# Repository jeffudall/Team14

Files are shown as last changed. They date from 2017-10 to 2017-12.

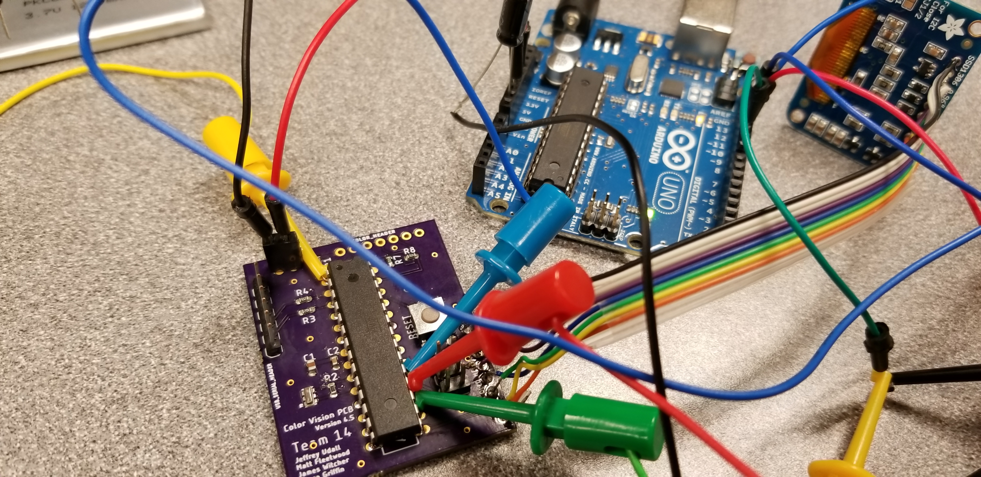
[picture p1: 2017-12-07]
images/20171201_192201.jpg

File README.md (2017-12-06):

Welcome to Team 14's Practicum Pages - ECE 411 Fall 2017

This repository will document our practicum project for the ECE 411 Industrial Design course at PSU for Fall 2017. Here you will find details of our project creation as well as documentation detailing the specifications and operation of our final product - a color scanner device.

Team members:

- Matthew Fleetwood fleet@pdx.edu
- Bruce Griffin bruce7@pdx.edu
- Jeffrey Udall judall@pdx.edu
- James Witcher jwitcher@pdx.edu

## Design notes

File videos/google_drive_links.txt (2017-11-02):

Not sure how to upload videos (larger than 25 MB not accepted?) to git. 

Here's the google drive link to the video of the speaker working with the RGB sensor:

https://drive.google.com/a/pdx.edu/file/d/0B2xjN2Vtsn0jbUI3cDFJcDRBUm8/view?usp=sharing

Video of new LCD demo

https://drive.google.com/open?id=0B6vxZIn4T96eQ21icXgxQTdLRFE

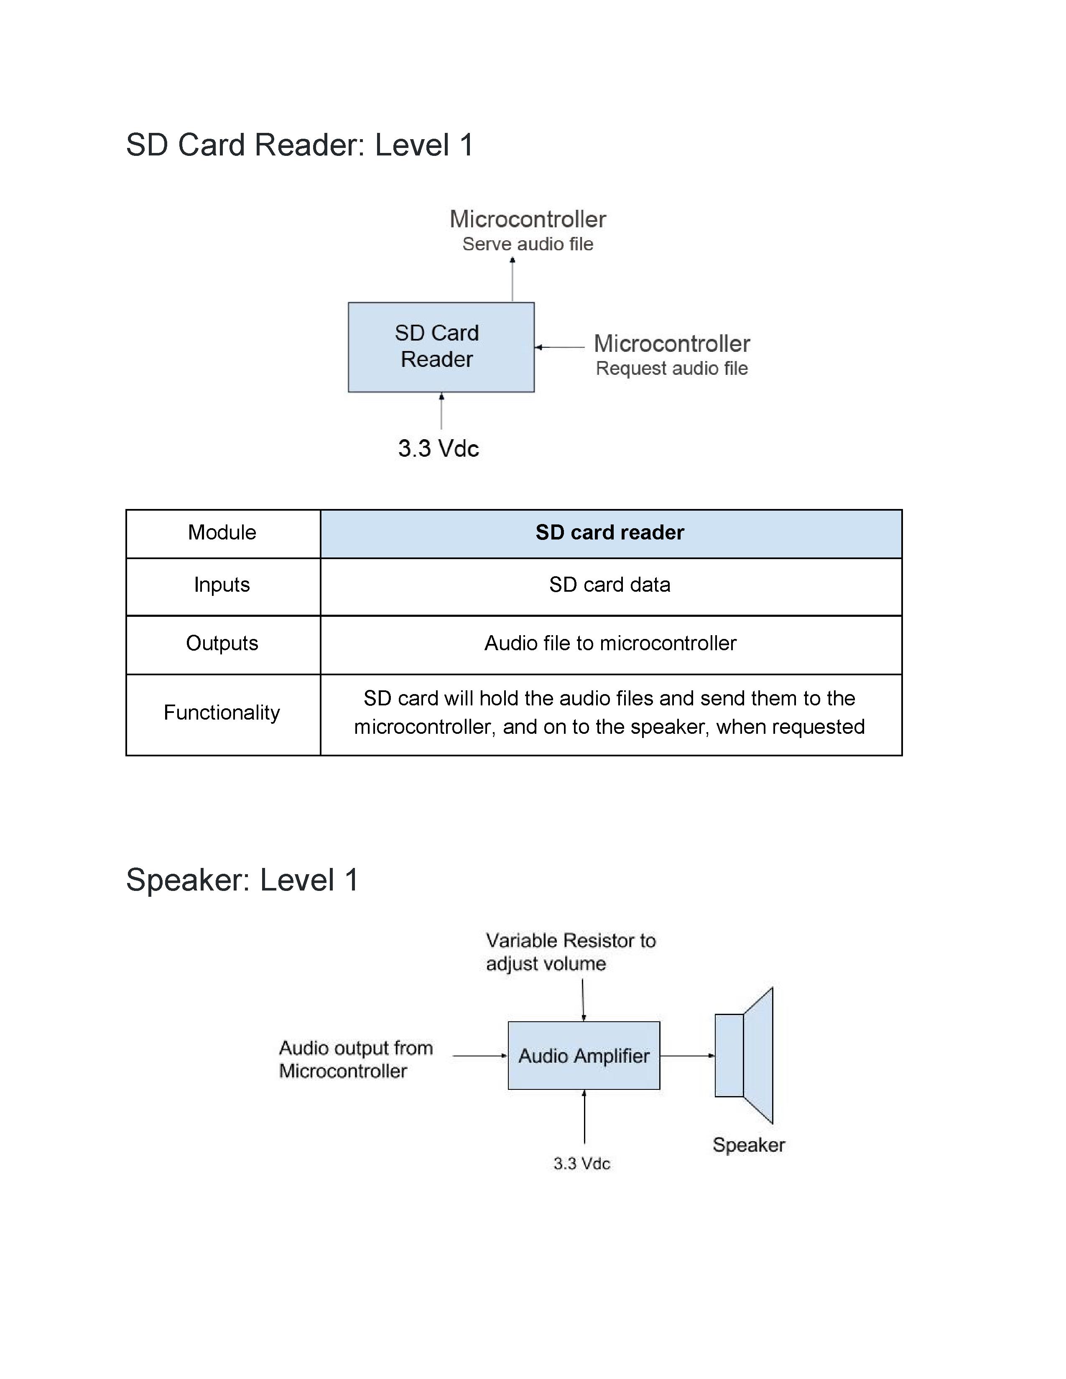
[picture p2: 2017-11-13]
images/HW5_group14_draft01-5.jpg

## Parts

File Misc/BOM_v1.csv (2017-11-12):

Part | Value | Device | Package | Description
C6 | 100n | C-EU0603-RND | C0603-ROUND | CAPACITOR, European symbol
COLOR_HEADER | COLOR_HEADER | HEADER-1X770MIL | 1X07_ROUND_70 | PIN HEADER
D2 | CD1206-S01575 | DIODE-MINIMELF | MINIMELF | DIODE
ICSP | 3x2 M | PINHD-2X3 | 2X03 | PIN HEADER
OLED_HEADER | OLED_HEADER | HEADER-1X870MIL | 1X08_ROUND_70 | PIN HEADER
POWER_IN | POWER_IN | PINHD-1X6 | 1X06 | PIN HEADER
POWER_SWITCH | POWER_SWITCH | EG1218S | EG1218 | SLIDING SWITCH
PSW_HEADER | PSW_HEADER | PINHD-1X6CB | 1X06-CLEANBIG | PIN HEADER
R2 | 1M | R-EU_R0603 | R0603-ROUND | RESISTOR, European symbol
RESET | TS42031-160R-TR-7260 | TS42 | TS42 | TS42
RN3 | 10K | 4R-NCAY16 | CAY16 | Array Chip Resistor
RN4 | 1K | 4R-NCAY16 | CAY16 | Array Chip Resistor
SCAN_BUTTON | SCAN_BUTTON | 31-XX | B3F-31XX | OMRON SWITCH
USB_SERIAL_HEADER | USB_SERIAL_HEADER | PINHD-1X6 | 1X06 | PIN HEADER
Y2 | CSTCE16M0V53-R0 16MHZ | RESONATORMU | RESONATOR
ZU4 | ATMEGA328P-PU | ATMEGA328P-PU | DIL28-3 | MICROCONTROLLER

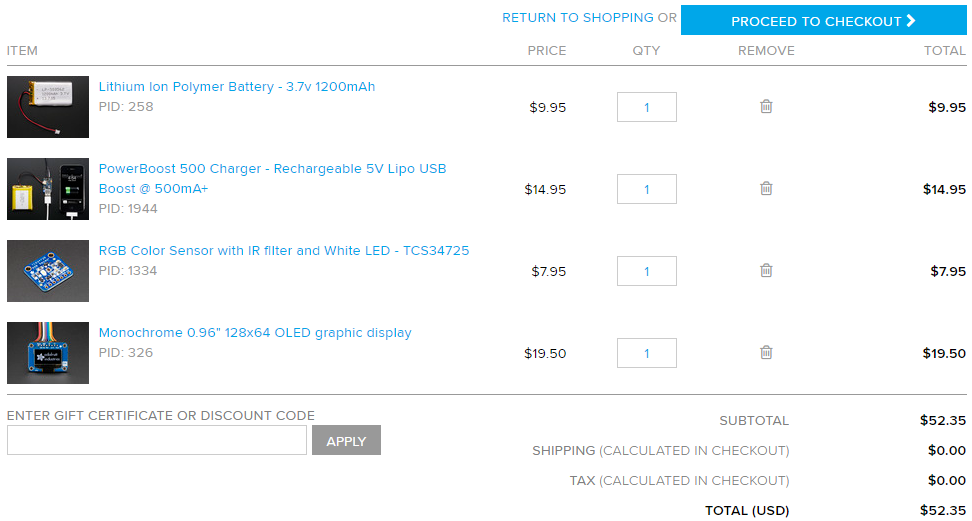
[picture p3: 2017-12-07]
images/bom.PNG

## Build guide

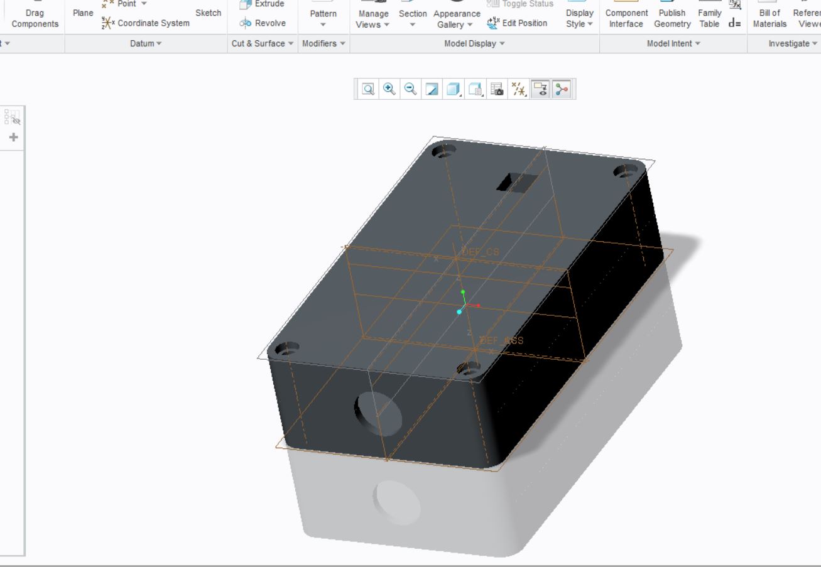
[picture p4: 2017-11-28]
images/Assemble_V2.JPG

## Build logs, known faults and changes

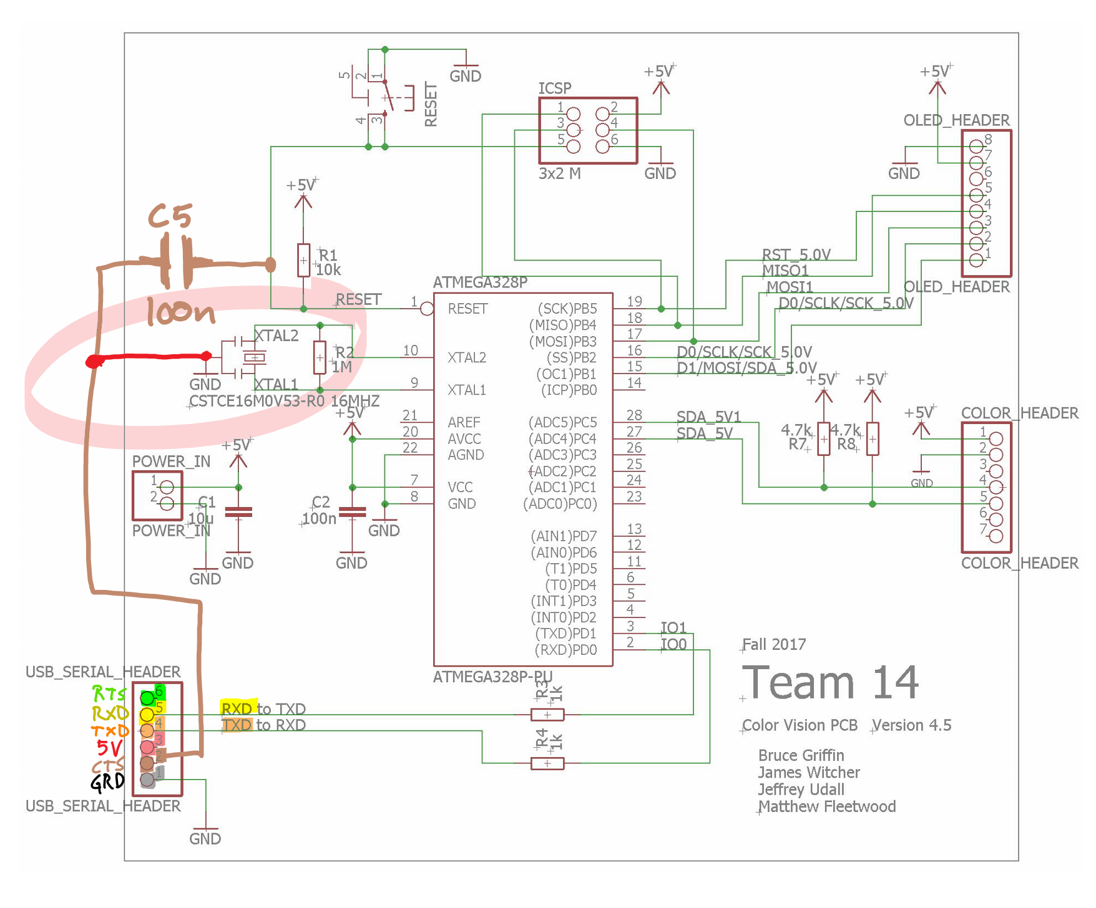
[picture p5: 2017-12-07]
images/Programing chip/Troubleshooting/Pasted image at 2017_12_03 10_22 AM (1).png

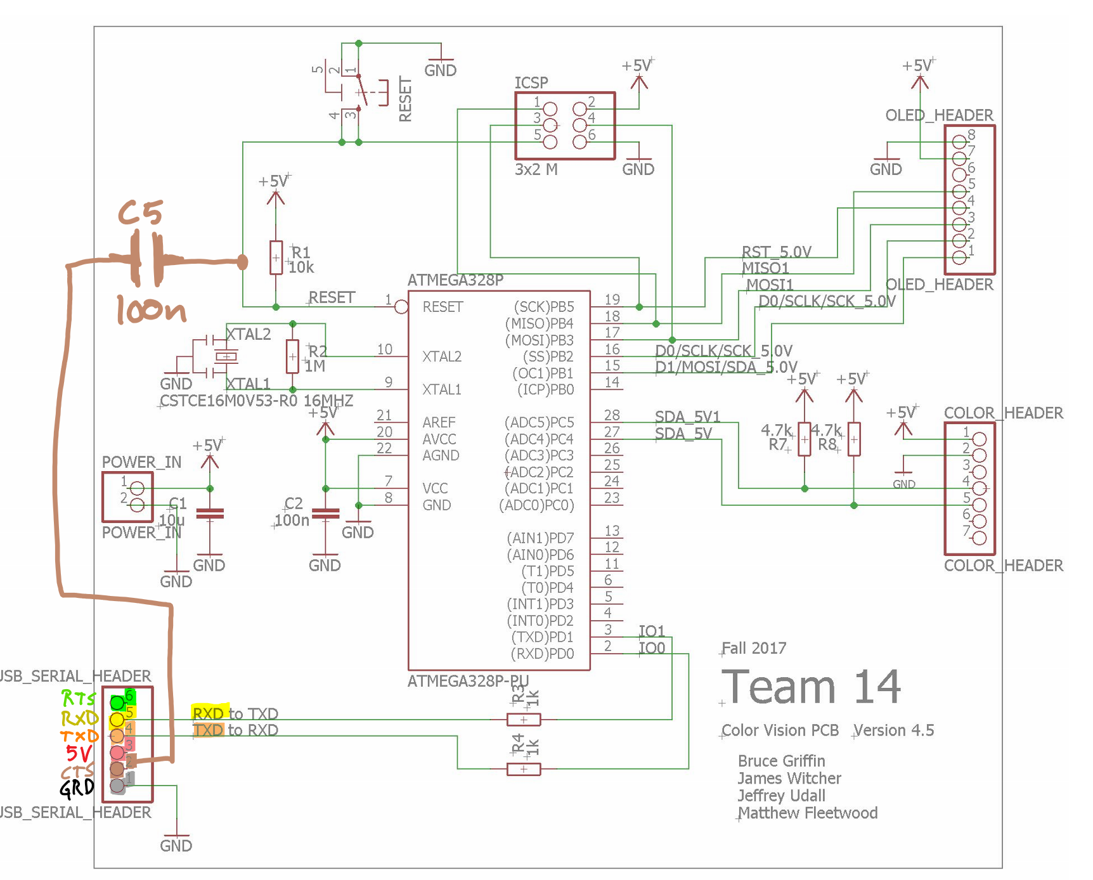
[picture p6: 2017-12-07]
images/Programing chip/Troubleshooting/Pasted image at 2017_12_03 10_20 AM.png

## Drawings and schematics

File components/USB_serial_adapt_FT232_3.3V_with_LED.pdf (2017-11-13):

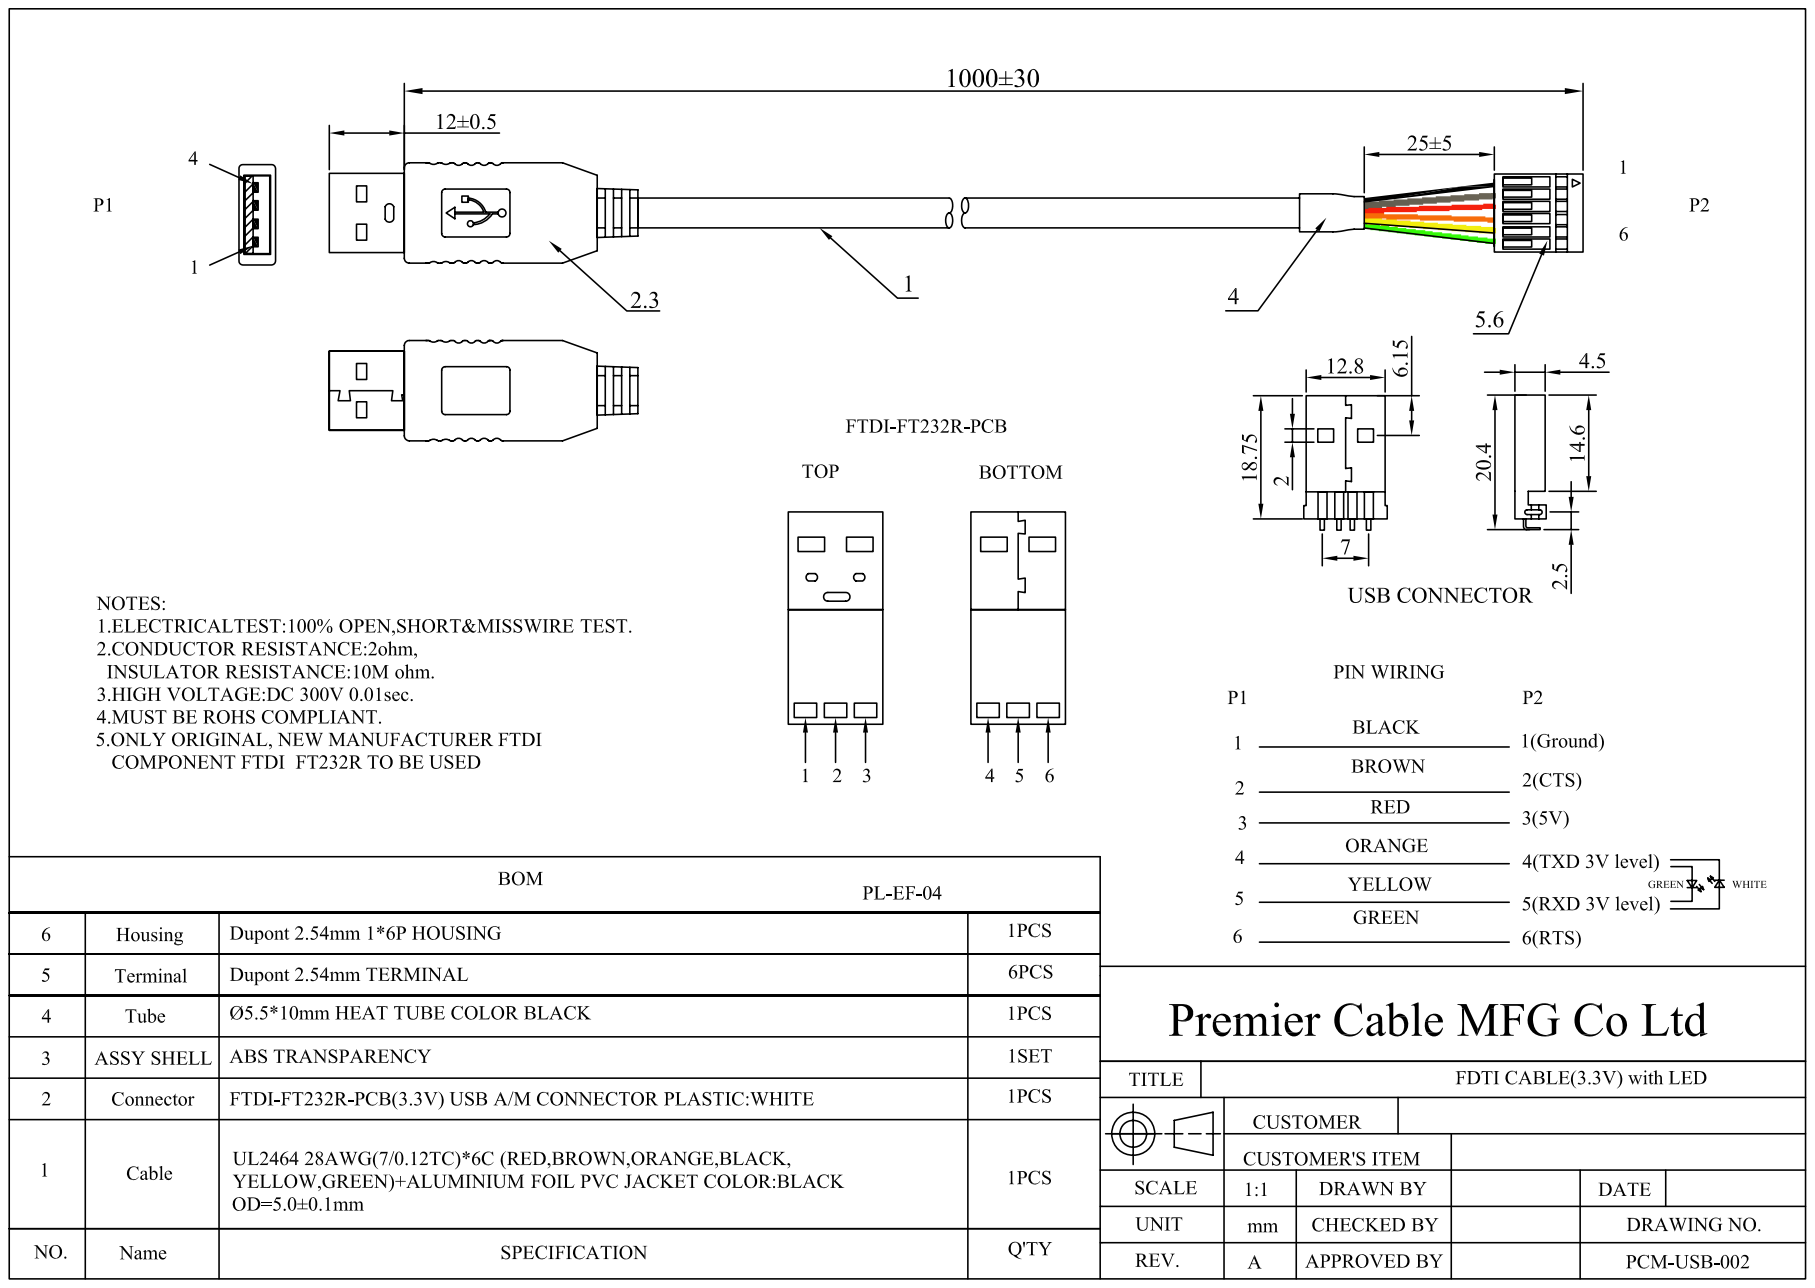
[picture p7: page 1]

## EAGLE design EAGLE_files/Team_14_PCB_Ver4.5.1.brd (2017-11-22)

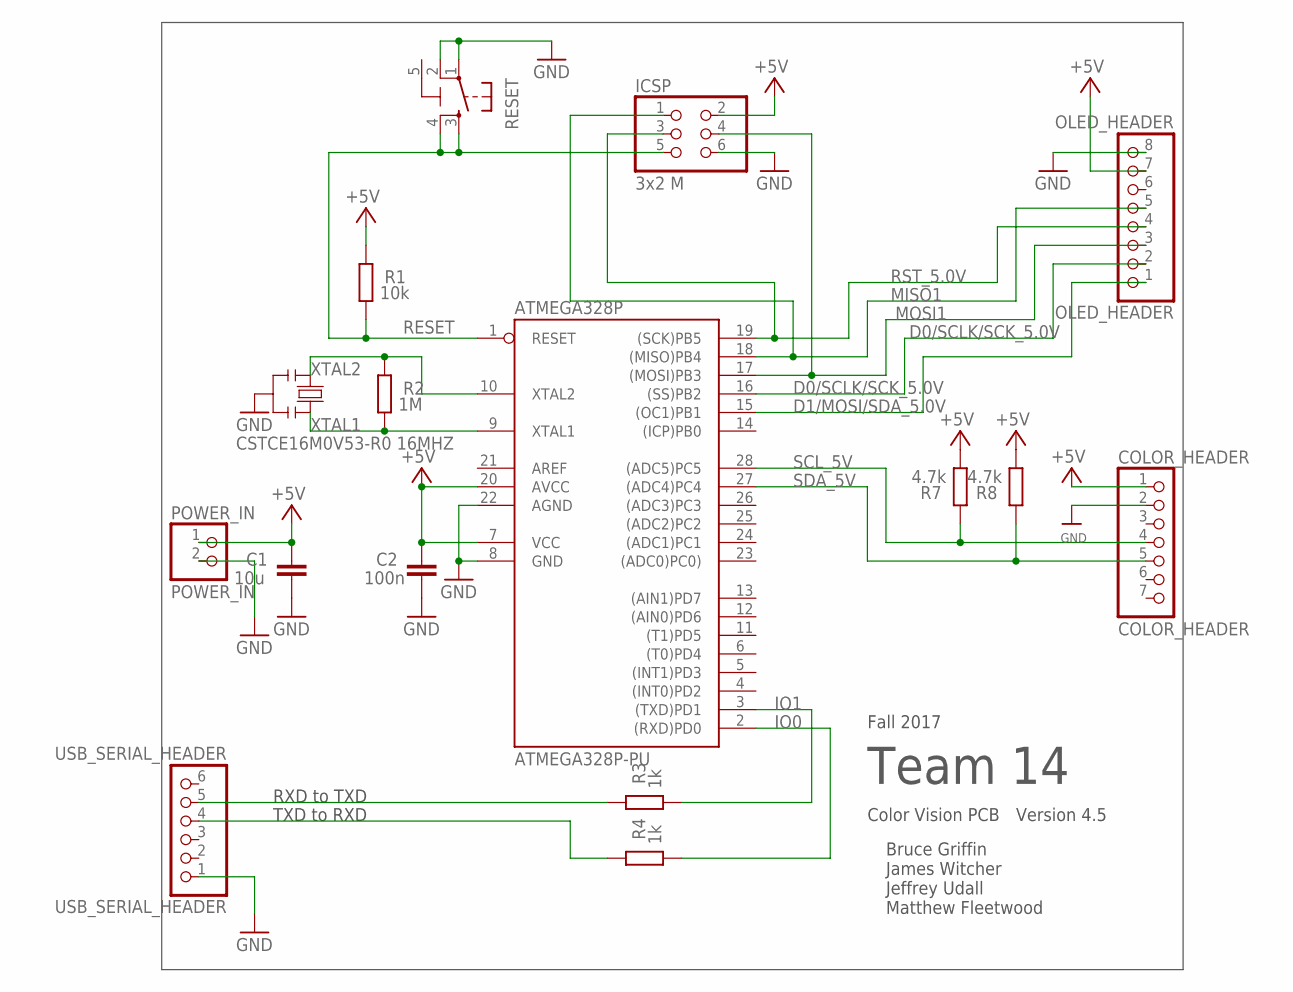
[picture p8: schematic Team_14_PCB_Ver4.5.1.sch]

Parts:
ATMEGA328P: ATMEGA328P-PU; DIL28-3
C1: 10u; C0603-ROUND
C2: 100n; C0603-ROUND
COLOR_HEADER: COLOR_HEADER; 1X07_ROUND_70
ICSP: 3x2 M; 2X03
OLED_HEADER: OLED_HEADER; 1X08_ROUND_70
POWER_IN: POWER_IN; 1X02
R1: 10k; R0603-ROUND
R2: 1M; R0603-ROUND
R3, R4: 1k; R0603-ROUND
R7, R8: 4.7k; R0603-ROUND
RESET: TS42
USB_SERIAL_HEADER: USB_SERIAL_HEADER; 1X06
Y2: CSTCE16M0V53-R0 16MHZ; RESONATOR

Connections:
5-GND: RESET.5 (5-GND)
+5V: ATMEGA328P.7 (VCC), ATMEGA328P.20 (AVCC), C1.2, C2.2, COLOR_HEADER.1, ICSP.2, OLED_HEADER.7, POWER_IN.1, R1.2, R7.1, R8.1
D0/SCLK/SCK_5.0V: ATMEGA328P.16 ((SS)PB2), OLED_HEADER.2
D1/MOSI/SDA_5.0V: ATMEGA328P.15 ((OC1)PB1), OLED_HEADER.1
GND: ATMEGA328P.8 (GND), ATMEGA328P.22 (AGND), C1.1, C2.1, COLOR_HEADER.2, ICSP.6, OLED_HEADER.8, POWER_IN.2, RESET.1, RESET.2, USB_SERIAL_HEADER.1, Y2.2
IO0: ATMEGA328P.2 ((RXD)PD0), R4.1
IO1: ATMEGA328P.3 ((TXD)PD1), R3.1
MISO1: ATMEGA328P.18 ((MISO)PB4), ICSP.1, OLED_HEADER.5
MOSI1: ATMEGA328P.17 ((MOSI)PB3), ICSP.4, OLED_HEADER.3
unnamed: R3.2, USB_SERIAL_HEADER.5
unnamed: R4.2, USB_SERIAL_HEADER.4
RESET: ATMEGA328P.1 (RESET), ICSP.5, R1.1, RESET.3, RESET.4
RST_5.0V: ATMEGA328P.19 ((SCK)PB5), ICSP.3, OLED_HEADER.4
SCL_5V: ATMEGA328P.28 ((ADC5)PC5), COLOR_HEADER.4, R7.2
SDA_5V: ATMEGA328P.27 ((ADC4)PC4), COLOR_HEADER.5, R8.2
XTAL1: ATMEGA328P.9 (XTAL1), R2.1, Y2.3
XTAL2: ATMEGA328P.10 (XTAL2), R2.2, Y2.1

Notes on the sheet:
Team 14
Bruce Griffin James Witcher Jeffrey Udall Matthew Fleetwood
Color Vision PCB
Version 4.5
Fall 2017
RXD to TXD
TXD to RXD

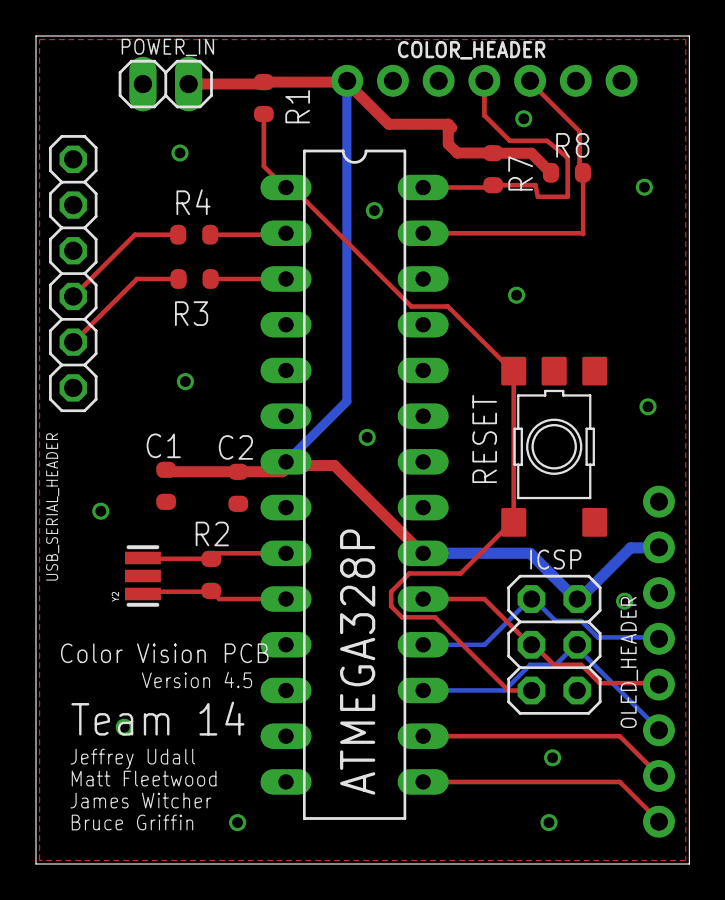
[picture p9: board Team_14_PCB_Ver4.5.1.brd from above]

Board: 2 copper layers, 36.3 x 46.0 mm, 16 parts (0 on the bottom side), 16 nets.

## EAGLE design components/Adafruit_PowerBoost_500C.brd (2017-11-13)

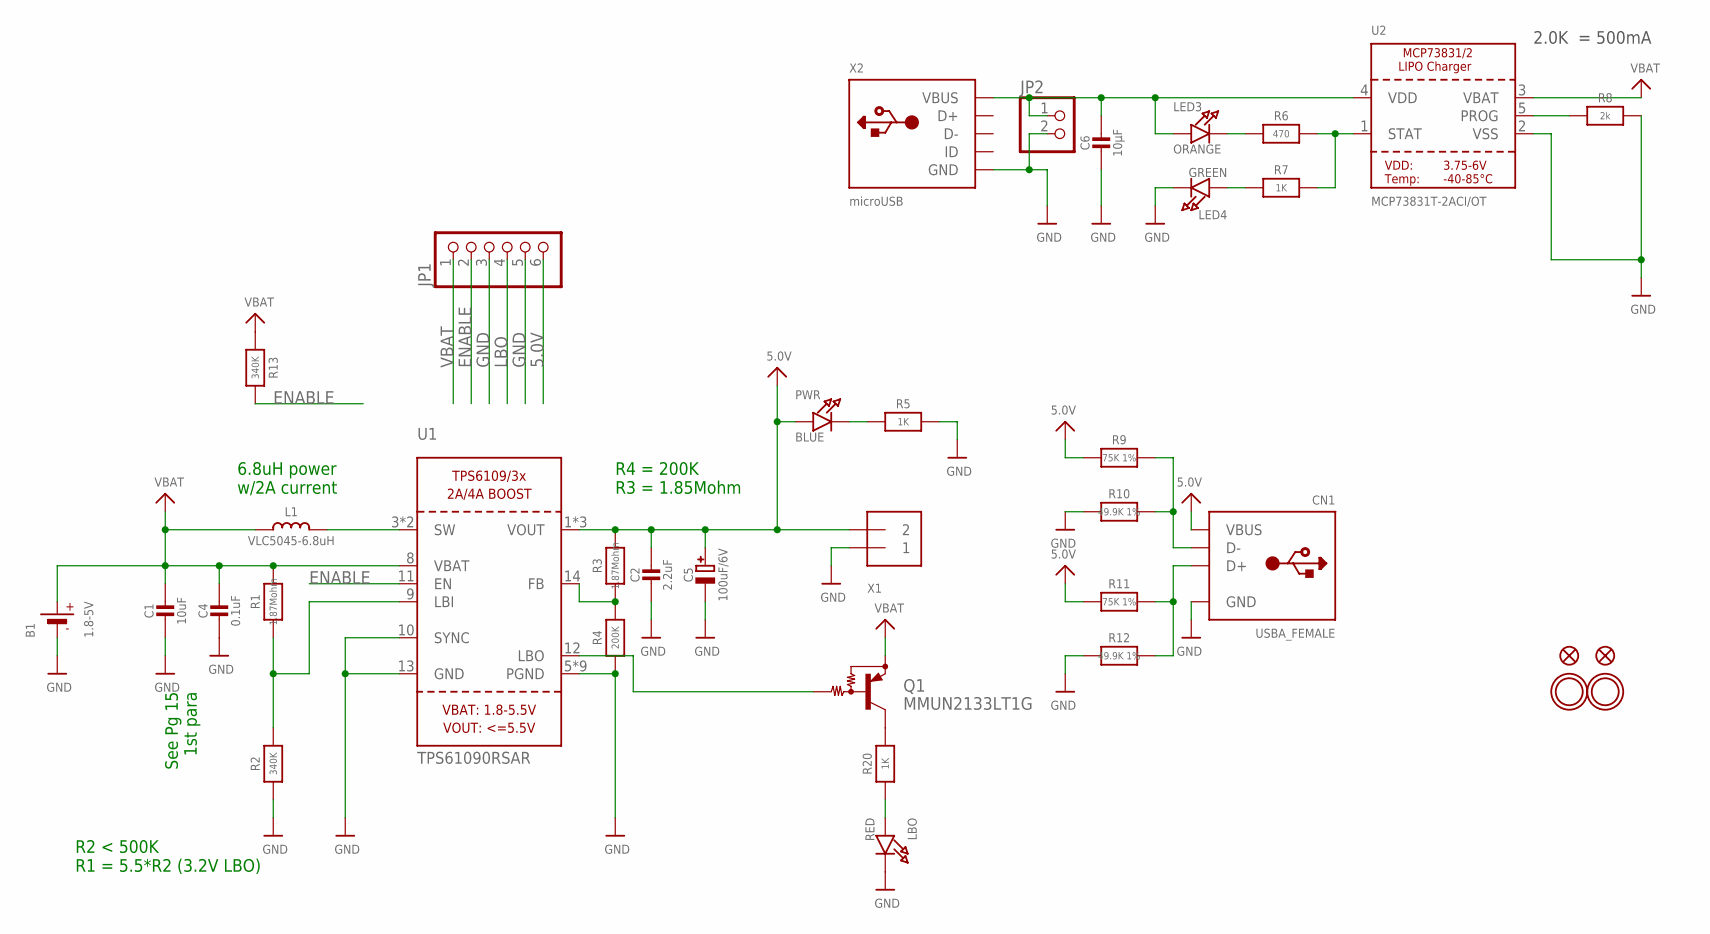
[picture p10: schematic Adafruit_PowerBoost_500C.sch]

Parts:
B1: 1.8-5V; JSTPH2
C1: 10uF; 0805-NO
C2: 2.2uF; 0805-NO
C4: 0.1uF; 0805-NO
C5: 100uF/6V; EIA3528-21/B-R
C6: 10µF; 0805-NO
CN1: USBA_FEMALE; USB_HOST-PTH
FID2, FID3: FIDUCIAL""; FIDUCIAL_1MM
JP1: PINHD-1X6CB; 1X06-CLEANBIG
JP2: HEADER-1X2ROUND; 1X02_ROUND
L1: VLC5045-6.8uH; INDUCTOR_5X5MM_TDK_VLC5045
LBO: RED; CHIPLED_0805_NOOUTLINE
LED3: ORANGE; CHIPLED_0805_NOOUTLINE
LED4: GREEN; CHIPLED_0805_NOOUTLINE
PWR: BLUE; CHIPLED_0805_NOOUTLINE
Q1: MMUN2133LT1G; SC59-BEC
R1, R3: 1.87Mohm; 0805-NO
R2, R13: 340K; 0805-NO
R4: 200K; 0805-NO
R5, R7, R20: 1K; 0805-NO
R6: 470; 0805-NO
R8: 2k; 0805-NO
R9, R11: 75K 1%; 0805-NO
R10, R12: 49.9K 1%; 0805-NO
U1: TPS61090RSAR; PVQFN-16
U2: MCP73831T-2ACI/OT; SOT23-5
U$10, U$12: MOUNTINGHOLE2.5; MOUNTINGHOLE_2.5_PLATED
X1: TERMBLOCK_1X2; TERMBLOCK_1X2-3.5MM
X2: microUSB; 4UCONN_20329

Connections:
5.0V: C2.1, C5.+, CN1.VBUS, JP1.6, PWR.A, R3.2, R9.2, R11.2, U1.1 (VOUT), U1.15 (VOUT), U1.16 (VOUT), X1.2
D+: CN1.D+, R11.1, R12.1
D-: CN1.D-, R9.1, R10.1
ENABLE: JP1.2, R13.2, U1.11 (EN)
GND: B1.1 (-), C1.2, C2.2, C4.2, C5.-, C6.2, CN1.GND, JP1.3, JP1.5, JP2.2, LBO.C, LED4.C, R2.1, R4.1, R5.2, R8.2, R10.2, R12.2, U1.5 (PGND), U1.6 (PGND), U1.7 (PGND), U1.10 (SYNC), U1.13 (GND), U1.P$18 (PGND), U1.P$19 (PGND), U1.P$20 (PGND), U1.P$21 (PGND), U1.P$22 (PGND), U1.THERMAL (PGND), U2.2 (VSS), X1.1, X2.BASE@1 (GND), X2.BASE@2 (GND), X2.GND, X2.SPRT@1 (GND), X2.SPRT@2 (GND), X2.SPRT@3 (GND), X2.SPRT@4 (GND)
LBO: JP1.4, Q1.B, U1.12 (LBO)
unnamed: L1.P$2 (2), U1.3 (SW), U1.4 (SW)
unnamed: LBO.A, R20.1
unnamed: R1.1, R2.2, U1.9 (LBI)
unnamed: PWR.C, R5.1
unnamed: R3.1, R4.2, U1.14 (FB)
unnamed: LED3.C, R6.1
unnamed: R6.2, R7.2, U2.1 (STAT)
unnamed: R8.1, U2.5 (PROG)
unnamed: LED4.A, R7.1
unnamed: Q1.C, R20.2
VBAT: B1.2 (+), C1.1, C4.1, JP1.1, L1.P$1 (1), Q1.E, R1.2, R13.1, U1.8 (VBAT), U2.3 (VBAT)
VDD1: C6.1, JP2.1, LED3.A, U2.4 (VDD), X2.VBUS

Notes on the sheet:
See Pg 15 1st para
6.8uH power w/2A current
R2 < 500K R1 = 5.5*R2 (3.2V LBO)
R4 = 200K R3 = 1.85Mohm
2.0K = 500mA

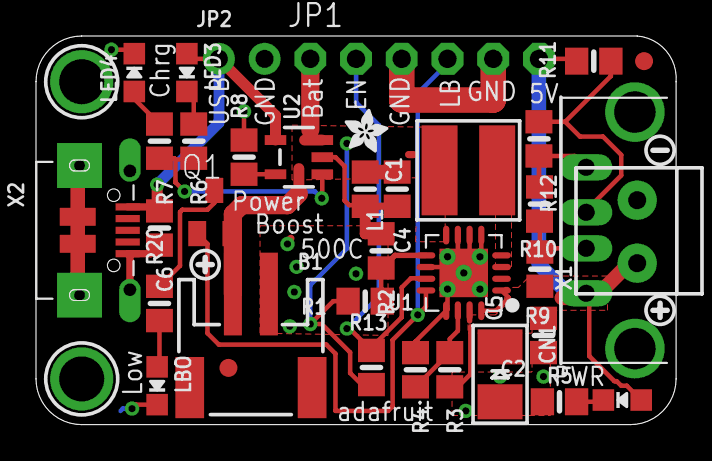
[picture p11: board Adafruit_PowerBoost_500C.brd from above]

Board: 2 copper layers, 35.6 x 21.6 mm, 42 parts (1 on the bottom side), 18 nets.

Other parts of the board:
U$13, U$25: SYMBOL_PLUS
U$26: SYMBOL_MINUS
U$28: ADAFRUIT_2.5MM
U$29: ADAFRUIT_5MM

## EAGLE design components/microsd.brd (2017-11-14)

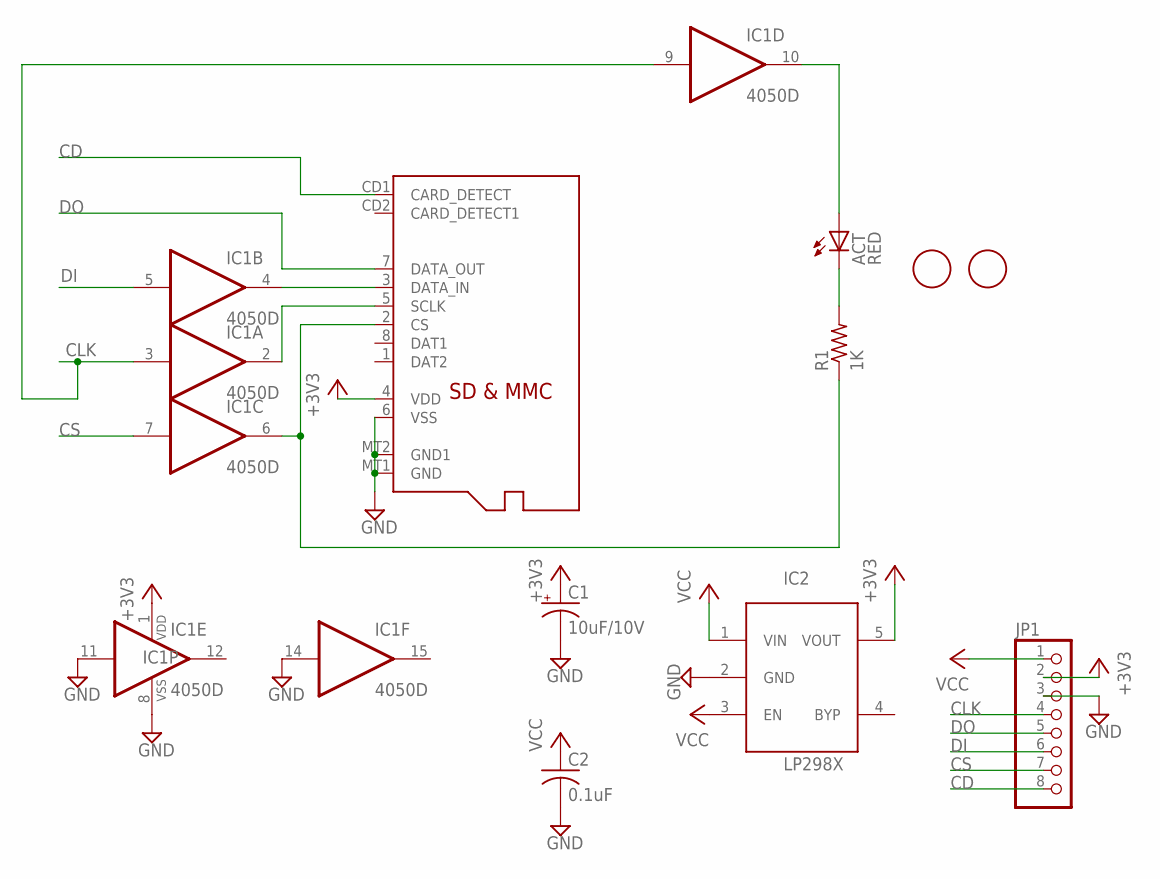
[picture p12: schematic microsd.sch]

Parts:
ACT: RED; CHIP-LED0805
C1: 10uF/10V; A/3216-18R
C2: 0.1uF; C0805K
IC1: 4050D; SO16
IC2: LP298XS; SOT23-5L
JP1: PINHD-1X8BIG; 1X08-BIG
R1: 1K; R0805
U$1, U$2: FIDUCIAL; FIDUCIAL_1MM
X1: MICROSD

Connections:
+3V3: C1.+, IC1.1 (VDD), IC2.5 (VOUT), JP1.2, X1.4 (VDD)
CD: JP1.8, X1.CD1 (CARD_DETECT)
CLK: IC1.3 (I), IC1.9 (I), JP1.4
CS: IC1.7 (I), JP1.7
DI: IC1.5 (I), JP1.6
DO: JP1.5, X1.7 (DATA_OUT)
GND: C1.-, C2.2, IC1.8 (VSS), IC1.11 (I), IC1.14 (I), IC2.2 (GND), JP1.3, X1.6 (VSS), X1.MT1 (GND), X1.MT2 (GND1)
unnamed: ACT.A, IC1.10 (O)
unnamed: IC1.2 (O), X1.5 (SCLK)
unnamed: IC1.6 (O), R1.1, X1.2 (CS)
unnamed: ACT.C, R1.2
unnamed: IC1.4 (O), X1.3 (DATA_IN)
VCC: C2.1, IC2.1 (VIN), IC2.3 (EN), JP1.1

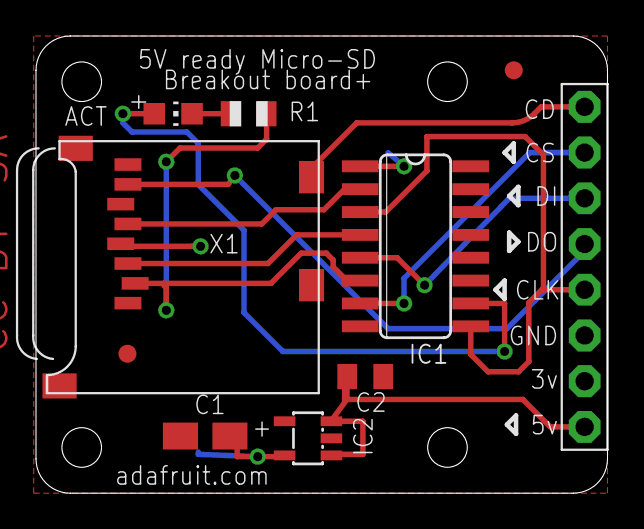
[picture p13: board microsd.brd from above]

Board: 2 copper layers, 31.8 x 25.4 mm, 10 parts (0 on the bottom side), 13 nets.

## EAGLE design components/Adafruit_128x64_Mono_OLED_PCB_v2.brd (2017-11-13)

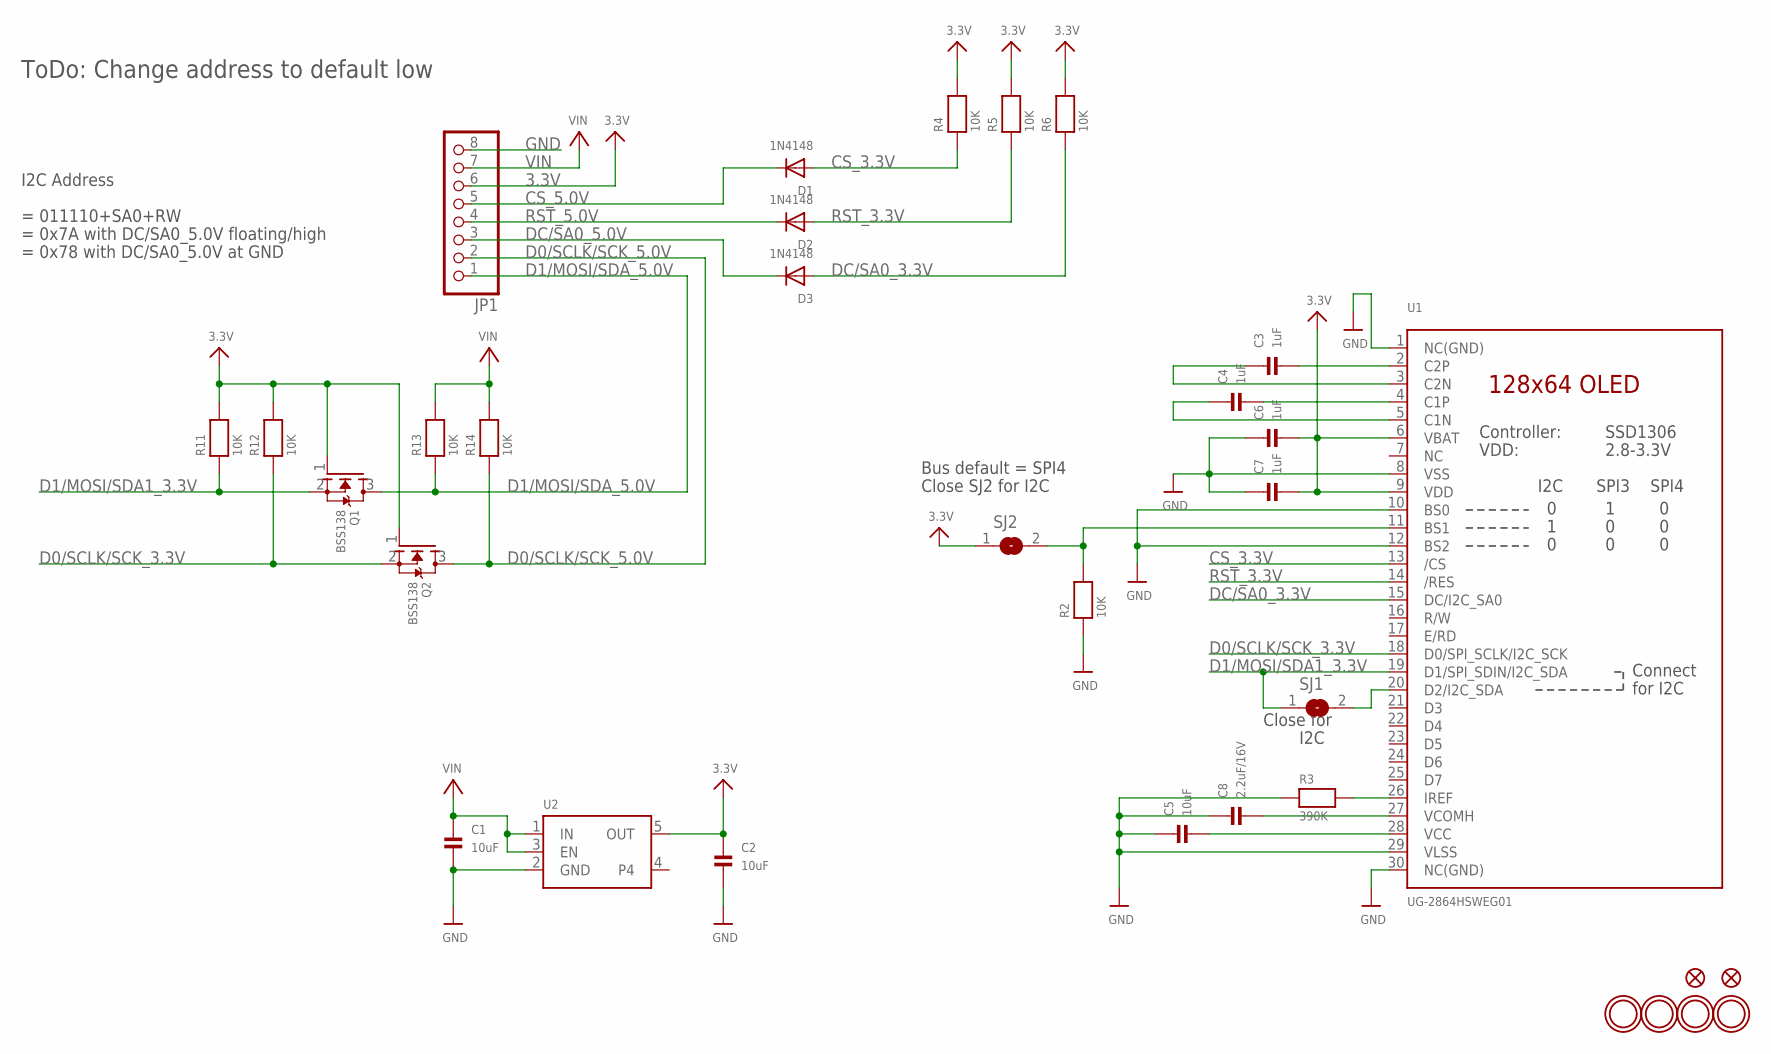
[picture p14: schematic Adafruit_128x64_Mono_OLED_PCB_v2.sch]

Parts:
C1, C2, C5: 10uF; 0805
C3, C4, C6, C7: 1uF; 0805
C8: 2.2uF/16V; 0805
D1, D2, D3: 1N4148; SOD-323
FID1, FID2: FIDUCIAL""; FIDUCIAL_1MM
JP1: HEADER-1X870MIL; 1X08_ROUND_70
Q1, Q2: BSS138; SOT23-WIDE
R2, R4, R5, R6, R11, R12, R13, R14: 10K; 0805
R3: 390K; 0805
SJ1, SJ2: SOLDERJUMPERREFLOW_NOPASTE; SOLDERJUMPER_REFLOW_NOPASTE
U1: UG-2864HSWEG01; UG-2864HSWEG01_0.96IN_WRAPAROUND
U2: VREG_SOT23-5; SOT23-5
U$23, U$24, U$25, U$26: MOUNTINGHOLE2.5; MOUNTINGHOLE_2.5_PLATED

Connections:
3.3V: C2.1, C6.2, C7.2, JP1.6, Q1.1 (G), Q2.1 (G), R4.2, R5.2, R6.2, R11.2, R12.2, SJ2.1, U1.6 (VBAT), U1.9 (VDD), U2.5 (OUT)
CS_3.3V: D1.A, R4.1, U1.13 (/CS)
CS_5.0V: D1.C, JP1.5
D0/SCLK/SCK_3.3V: Q2.2 (S), R12.1, U1.18 (D0/SPI_SCLK/I2C_SCK)
D0/SCLK/SCK_5.0V: JP1.2, Q2.3 (D), R14.1
D1/MOSI/SDA1_3.3V: Q1.2 (S), R11.1, SJ1.1, U1.19 (D1/SPI_SDIN/I2C_SDA)
D1/MOSI/SDA_5.0V: JP1.1, Q1.3 (D), R13.1
DC/SA0_3.3V: D3.A, R6.1, U1.15 (DC/I2C_SA0)
DC/SA0_5.0V: D3.C, JP1.3
GND: C1.2, C2.2, C5.1, C6.1, C7.1, C8.1, JP1.8, R2.1, R3.1, U1.1 (NC(GND)), U1.8 (VSS), U1.10 (BS0), U1.12 (BS2), U1.29 (VLSS), U1.30 (NC(GND)), U2.2 (GND)
unnamed: R2.2, SJ2.2, U1.11 (BS1)
unnamed: SJ1.2, U1.20 (D2/I2C_SDA)
unnamed: R3.2, U1.26 (IREF)
unnamed: C3.2, U1.2 (C2P)
unnamed: C3.1, U1.3 (C2N)
unnamed: C4.2, U1.4 (C1P)
unnamed: C4.1, U1.5 (C1N)
unnamed: C5.2, U1.28 (VCC)
unnamed: C8.2, U1.27 (VCOMH)
RST_3.3V: D2.A, R5.1, U1.14 (/RES)
RST_5.0V: D2.C, JP1.4
VIN: C1.1, JP1.7, R13.2, R14.2, U2.1 (IN), U2.3 (EN)

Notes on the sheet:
Bus default = SPI4
Close SJ2 for I2C
= 011110+SA0+RW
= 0x7A with DC/SA0_5.0V floating/high
= 0x78 with DC/SA0_5.0V at GND
I2C Address
ToDo: Change address to default low
Close for
I2C

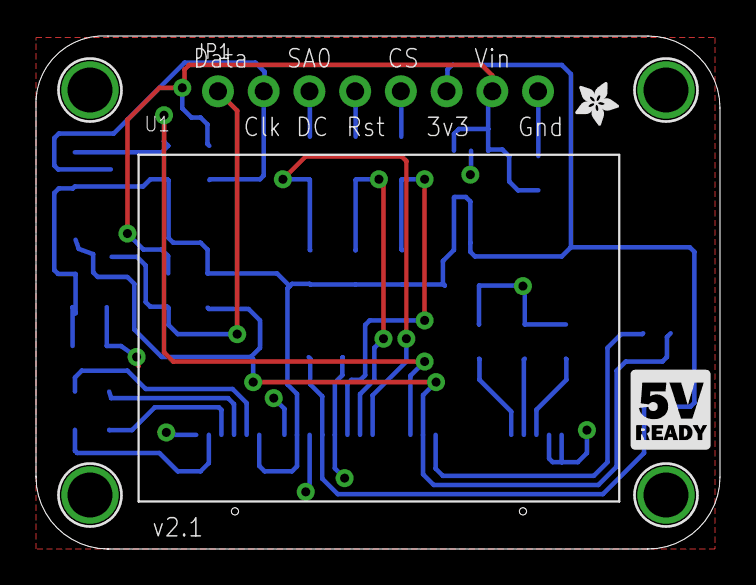
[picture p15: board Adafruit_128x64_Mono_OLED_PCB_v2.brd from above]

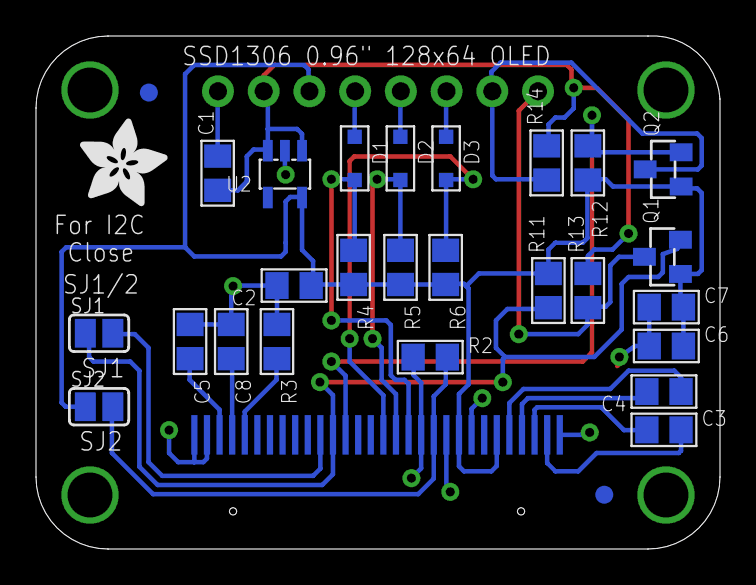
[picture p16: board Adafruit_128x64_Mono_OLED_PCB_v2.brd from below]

Board: 2 copper layers, 38.0 x 28.5 mm, 36 parts (28 on the bottom side), 22 nets.

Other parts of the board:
U$3: ADAFRUIT_5MM
U$27: ADAFRUIT_2.5MM
U$28: LOGIC_5VREADY_5MM

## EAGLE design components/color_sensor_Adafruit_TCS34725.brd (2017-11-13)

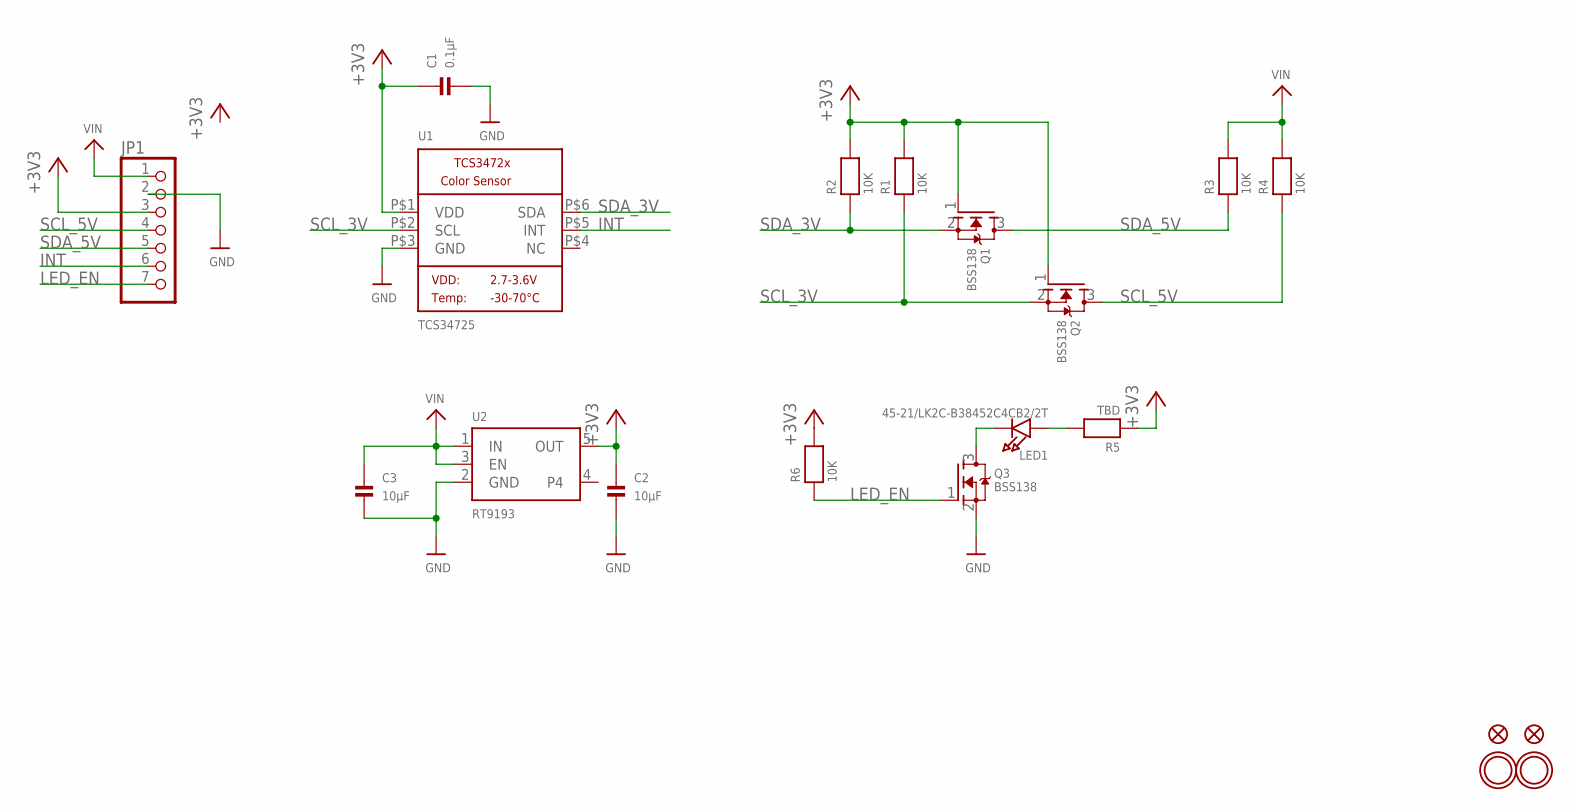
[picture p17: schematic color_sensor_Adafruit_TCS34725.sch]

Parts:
C1: 0.1µF; _0805
C2, C3: 10µF; _0805
FID1, FID2: FIDUCIAL""; FIDUCIAL_1MM
JP1: HEADER-1X770MIL; 1X07_ROUND_70
LED1: 45-21/LK2C-B38452C4CB2/2T; EVERLIGHT_45-21
Q1, Q2, Q3: BSS138; SOT23-WIDE
R1, R2, R3, R4, R6: 10K; _0805
R5: TBD; _0805
U1: TCS34725; TCS3472_FN6
U2: RT9193; SOT23-5
U$8, U$14: MOUNTINGHOLE2.5; MOUNTINGHOLE_2.5_PLATED

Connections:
+3V3: C1.1, C2.1, JP1.3, Q1.1 (G), Q2.1 (G), R1.2, R2.2, R5.1, R6.2, U1.P$1 (VDD), U2.5 (OUT)
GND: C1.2, C2.2, C3.2, JP1.2, Q3.2 (S), U1.P$3 (GND), U2.2 (GND)
INT: JP1.6, U1.P$5 (INT)
LED_EN: JP1.7, Q3.1 (G), R6.1
unnamed: LED1.K (C), Q3.3 (D)
unnamed: LED1.A, R5.2
SCL_3V: Q2.2 (S), R1.1, U1.P$2 (SCL)
SCL_5V: JP1.4, Q2.3 (D), R4.1
SDA_3V: Q1.2 (S), R2.1, U1.P$6 (SDA)
SDA_5V: JP1.5, Q1.3 (D), R3.1
VIN: C3.1, JP1.1, R3.2, R4.2, U2.1 (IN), U2.3 (EN)

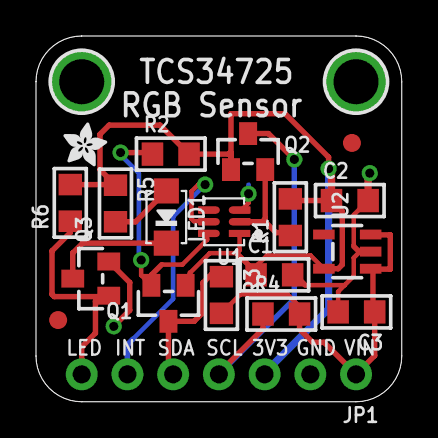
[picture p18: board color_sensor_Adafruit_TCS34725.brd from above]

Board: 2 copper layers, 20.3 x 20.3 mm, 22 parts (1 on the bottom side), 11 nets.

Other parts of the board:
U$2: ADAFRUIT_2.5MM
U$18: ADAFRUIT_5MM

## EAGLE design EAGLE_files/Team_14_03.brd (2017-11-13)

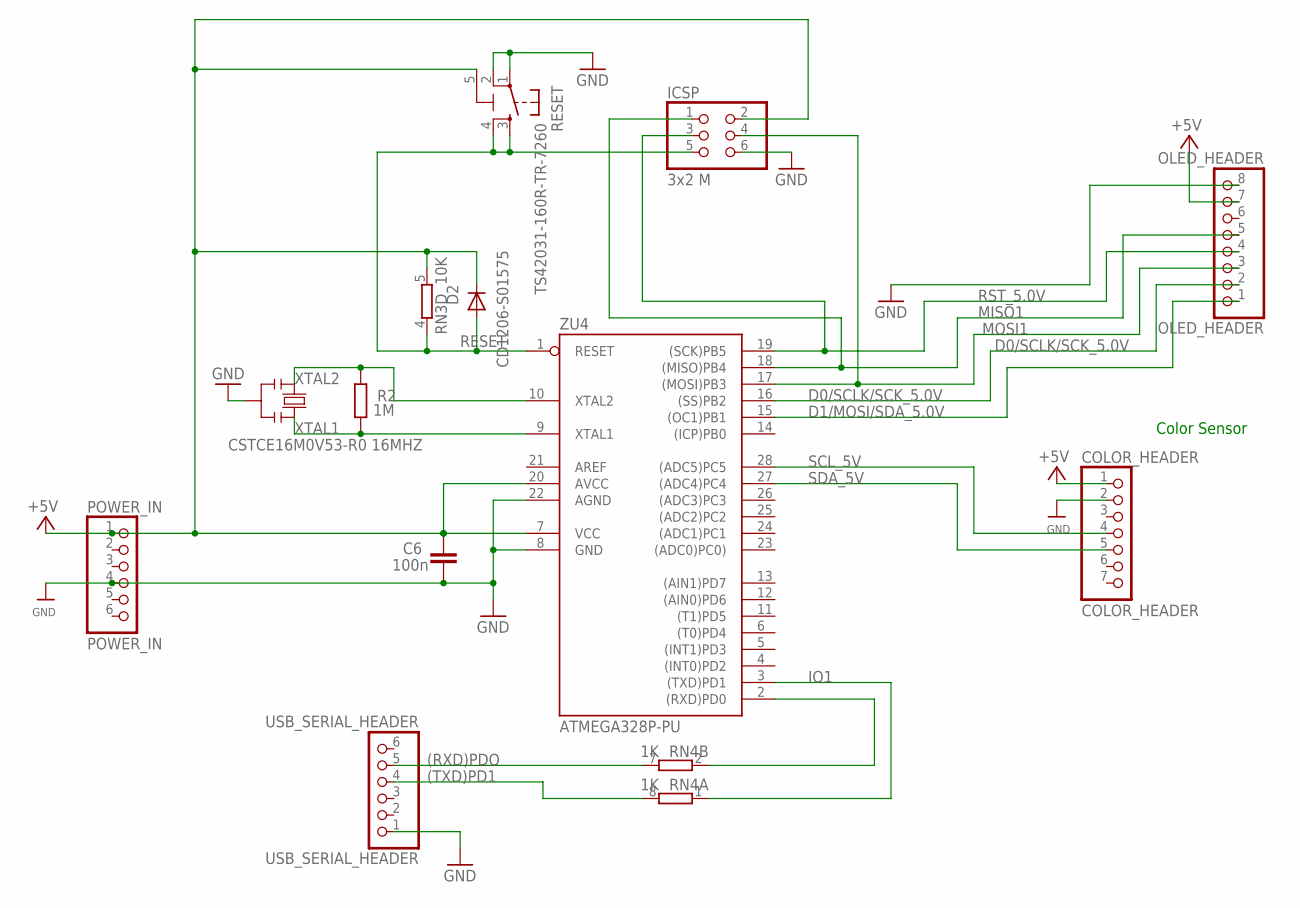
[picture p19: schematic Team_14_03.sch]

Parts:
C6: 100n; C0603-ROUND
COLOR_HEADER: COLOR_HEADER; 1X07_ROUND_70
D2: CD1206-S01575; MINIMELF
ICSP: 3x2 M; 2X03
OLED_HEADER: OLED_HEADER; 1X08_ROUND_70
POWER_IN: POWER_IN; 1X06
R2: 1M; R0603-ROUND
RESET: TS42031-160R-TR-7260; TS42
RN3: 10K; CAY16
RN4: 1K; CAY16
USB_SERIAL_HEADER: USB_SERIAL_HEADER; 1X06
Y2: CSTCE16M0V53-R0 16MHZ; RESONATOR
ZU4: ATMEGA328P-PU; DIL28-3

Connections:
(RXD)PDO: RN4.7 (2), USB_SERIAL_HEADER.5
(TXD)PD1: RN4.8 (2), USB_SERIAL_HEADER.4
+5V: C6.2, COLOR_HEADER.1, D2.C, ICSP.2, OLED_HEADER.7, POWER_IN.1, RESET.5 (5-GND), RN3.5 (2), ZU4.7 (VCC), ZU4.20 (AVCC)
D0/SCLK/SCK_5.0V: OLED_HEADER.2, ZU4.16 ((SS)PB2)
D1/MOSI/SDA_5.0V: OLED_HEADER.1, ZU4.15 ((OC1)PB1)
GND: C6.1, COLOR_HEADER.2, ICSP.6, OLED_HEADER.8, POWER_IN.4, RESET.1, RESET.2, USB_SERIAL_HEADER.1, Y2.2, ZU4.8 (GND), ZU4.22 (AGND)
IO1: RN4.1, ZU4.3 ((TXD)PD1)
IO11: RN4.2 (1), ZU4.2 ((RXD)PD0)
MISO1: ICSP.1, OLED_HEADER.5, ZU4.18 ((MISO)PB4)
MOSI1: ICSP.4, OLED_HEADER.3, ZU4.17 ((MOSI)PB3)
RESET: D2.A, ICSP.5, RESET.3, RESET.4, RN3.4 (1), ZU4.1 (RESET)
RST_5.0V: ICSP.3, OLED_HEADER.4, ZU4.19 ((SCK)PB5)
SCL_5V: COLOR_HEADER.4, ZU4.28 ((ADC5)PC5)
SDA_5V: COLOR_HEADER.5, ZU4.27 ((ADC4)PC4)
XTAL1: R2.1, Y2.3, ZU4.9 (XTAL1)
XTAL2: R2.2, Y2.1, ZU4.10 (XTAL2)

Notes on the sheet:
Color Sensor


Board: 2 copper layers, 53.0 x 40.6 mm, 13 parts (0 on the bottom side), 16 nets.

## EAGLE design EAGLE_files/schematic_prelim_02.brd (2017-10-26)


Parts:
AD: 6x1F-H8.5; 1X06
C1, C2, C4, C5, C6, C7: 100n; C0603-ROUND
C3, C8: 1u; C0603-ROUND
C9, C11: 22p; C0603-ROUND
C13: 0.1µF; _0805
C14, C15: 10µF; _0805
D1: M7; SMB
D2, D3: CD1206-S01575; MINIMELF
DIS1: EA_DIP
F1: MF-MSMF050-2 500mA; L1812
FD1, FD2, FD3: FIDUCIALMOUNT; FIDUCIA-MOUNT
GROUND: SJ
ICSP, ICSP1: 3x2 M; 2X03
IOH: 10x1F-H8.5; 1X10
IOL: 8x1F-H8.5; 1X08
JP1: HEADER-1X770MIL; 1X07_ROUND_70
JP2: 2x2 M - NM; 2X02
L: YELLOW; CHIP-LED0805
L1: BLM21; 0805
LED1: 45-21/LK2C-B38452C4CB2/2T; EVERLIGHT_45-21
ON: GREEN; CHIP-LED0805
PC1, PC2: 47u; PANASONIC_D
POWER: 8x1F-H8.5; 1X08
Q1, Q3, Q4: BSS138; SOT23-WIDE
R1, R2: 1M; R0603-ROUND
R3: TBD; _0805
R4, R5, R6, R7, R8: 10K; _0805
R9: TRIM_US-B25U; B25U
RESET: TS42031-160R-TR-7260; TS42
RESET-EN: SJ
RN1: 10K; CAY16
RN2, RN4: 1K; CAY16
RN3: 22R; CAY16
RX: YELLOW; CHIP-LED0805
SP1: SPEAKER/AL60P; AL60P
T1: FDN340P; SOT-23
TX: YELLOW; CHIP-LED0805
U1: NCP1117ST50T3G; SOT223
U2: LP2985-33DBVR; SOT23-DBV
U3: ATMEGA16U2-MU(R); MLF32
U4: TCS34725; TCS3472_FN6
U5: LMV358IDGKR; MSOP08
U6: RT9193; SOT23-5
U$1: DISCLAIMER
X1: POWERSUPPLY_DC21MMX; POWERSUPPLY_DC-21MM
X2: USB-B_TH; PN61729
Y1: 16MHz; QS
Y2: CSTCE16M0V53-R0 16MHZ; RESONATOR
Z1, Z2: CG0603MLC-05E; CT/CN0603
ZU4: ATMEGA328P-PU; DIL28-3

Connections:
5-GND: RESET.5 (5-GND)
+3V3: C3.2, C13.1, C15.1, JP1.3, POWER.4, Q3.1 (G), Q4.1 (G), R3.1, R4.2, R5.2, R8.2, U2.5 (OUT), U4.P$1 (VDD), U5.2 (-IN), U6.5 (OUT)
+5V: C1.2, C2.2, C6.2, C7.1, D2.C, D3.C, ICSP.2, ICSP1.2, JP1.1, PC2.+, POWER.2, POWER.5, RN1.3 (1), RN1.5 (2), RN2.2 (1), RN2.3 (1), RN4.3 (1), RN4.4 (1), T1.2 (S), U1.2 (OUT), U1.4 (OUT), U2.1 (IN), U2.3 (ON/!OFF), U3.4 (VCC), U3.32 (AVCC), U5.8 (V+), ZU4.7 (VCC), ZU4.20 (AVCC)
AD0: AD.1, ZU4.23 ((ADC0)PC0))
AD1: AD.2, ZU4.24 ((ADC1)PC1)
AD2: AD.3, ZU4.25 ((ADC2)PC2)
AD3: AD.4, ZU4.26 ((ADC3)PC3)
AD4/SDA: IOH.9
AD5/SCL: IOH.10
AREF: C4.2, IOH.8, ZU4.21 (AREF)
CMP: RN1.1, RN1.2 (1), U5.3 (+IN)
D+: RN3.5 (2), X2.3, Z1.1
D-: RN3.8 (2), X2.2, Z2.1
DTR: C5.1, RN2.4 (1), U3.13 ((CTS/HWB/AIN6/TO/INT7)PD7)
GATE_CMD: T1.3 (G), U5.1 (OUT)
GND: C1.1, C2.1, C3.1, C4.1, C6.1, C7.2, C9.2, C11.2, C13.2, C14.2, C15.2, DIS1.1 (VSS), DIS1.5 (R/W), DIS1.18 (C), GROUND.1, ICSP.6, ICSP1.6, IOH.7, JP1.2, L.C, ON.C, PC1.-, PC2.-, POWER.6, POWER.7, Q1.2 (S), R9.A, RESET.1, RESET.2, RN1.7 (2), RN2.5 (2), SP1.1 (+), U1.1 (GND/ADJ), U2.2 (GND), U3.3 (GND), U3.33 (PAD), U4.P$3 (GND), U5.4 (V-), U6.2 (GND), X1.1, X1.3, Y2.2, ZU4.8 (GND), ZU4.22 (AGND)
INT: JP1.6, U4.P$5 (INT)
IO0: IOL.1, RN4.2 (1), ZU4.2 ((RXD)PD0)
IO1: IOL.2, RN4.1, ZU4.3 ((TXD)PD1)
IO2: DIS1.14 (D7), IOL.3, ZU4.4 ((INT0)PD2)
IO3: DIS1.13 (D6), IOL.4, ZU4.5 ((INT1)PD3)
IO4: DIS1.12 (D5), IOL.5, ZU4.6 ((T0)PD4)
IO5: DIS1.11 (D4), IOL.6, ZU4.11 ((T1)PD5)
IO6: IOL.7, ZU4.12 ((AIN0)PD6)
IO7: IOL.8, ZU4.13 ((AIN1)PD7)
IO8: IOH.1, ZU4.14 ((ICP)PB0)
IO9: IOH.2, SP1.2 (-), ZU4.15 ((OC1)PB1)
L13: RN2.8 (2), U5.6 (-IN), U5.7 (OUT)
LED_EN: JP1.7, Q1.1 (G), R8.1
M8RXD: RN4.7 (2), U3.9 ((TXD1/INT3)PD3)
M8TXD: RN4.8 (2), U3.8 ((RXD1/AIN1/INT2)PD2)
MISO: DIS1.4 (RS), ICSP.1, IOH.5, ZU4.18 ((MISO)PB4)
MISO2: ICSP1.1, U3.17 ((PD0/MISO/PCINT3)PB3)
MOSI: DIS1.6 (E), ICSP.4, IOH.4, ZU4.17 ((MOSI)PB3)
MOSI2: ICSP1.4, U3.16 ((PDI/MOSI/PCINT2)PB2)
unnamed: L.A, RN2.1
unnamed: LED1.K (C), Q1.3 (D)
unnamed: ON.A, RN4.5 (2), RN4.6 (2)
unnamed: LED1.A, R3.2
unnamed: DIS1.2 (VDD), DIS1.3 (VEE), DIS1.17 (A), R9.E
unnamed: RN2.7 (2), RX.A
unnamed: RN2.6 (2), TX.A
PB4: JP2.1, U3.18 ((T1/PCINT4)PB4)
PB5: JP2.3, U3.19 ((PCINT5)PB5)
PB6: JP2.2, U3.20 ((PCINT6)PB6)
PB7: JP2.4, U3.21 ((PCINT7/OC0A/OC1C)PB7)
PWRIN: D1.A, X1.2
RD+: RN3.4 (1), U3.29 (D+)
RD-: RN3.1, U3.30 (D-)
RESET: C5.2, D2.A, ICSP.5, POWER.3, RESET.3, RESET.4, RESET-EN.1, RESET-EN.2, RN1.4 (1), ZU4.1 (RESET)
RESET2: D3.A, ICSP1.5, RN1.6 (2), U3.24 (RESET(PC1/DW))
RXLED: RX.C, U3.10 ((INT5/AIN3)PD4)
SCK: ICSP.3, IOH.6, U5.5 (+IN), ZU4.19 ((SCK)PB5)
SCK2: ICSP1.3, U3.15 ((SCLK/PCINT1)PB1)
SCL_3V: Q4.2 (S), R4.1, U4.P$2 (SCL)
SCL_5V: AD.6, JP1.4, Q4.3 (D), R7.1, ZU4.28 ((ADC5)PC5)
SDA_3V: Q3.2 (S), R5.1, U4.P$6 (SDA)
SDA_5V: AD.5, JP1.5, Q3.3 (D), R6.1, ZU4.27 ((ADC4)PC4)
SS: IOH.3, ZU4.16 ((SS)PB2)
TP_VUCAP: C8.1, U3.27 (UCAP)
TXLED: TX.C, U3.11 ((XCK/AIN4/PCINT12)PD5)
UGND: C8.2, GROUND.2, L1.1, U3.28 (UGND), X2.4
USBVCC: F1.1, T1.1 (D), U3.31 (UVCC)
USHIELD: L1.2, X2.P$1, X2.P$2, Z1.2, Z2.2
VIN: C14.1, D1.C, PC1.+, POWER.8, R6.2, R7.2, RN1.8 (2), U1.3 (IN), U6.1 (IN), U6.3 (EN)
XT1: C9.1, R1.1, U3.1 (XTAL1), Y1.2
XT2: C11.1, R1.2, U3.2 (XTAL2(PC0)), Y1.1
XTAL1: R2.1, Y2.3, ZU4.9 (XTAL1)
XTAL2: R2.2, Y2.1, ZU4.10 (XTAL2)
XUSB: F1.2, X2.1

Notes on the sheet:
Arduino(TM) UNO Rev3
USB boot En
SDA
SCL
Use of the ARDUINO name must be compliant with http://www.arduino.cc/en/Main/Policy
Color Sensor TCS34725
+5V

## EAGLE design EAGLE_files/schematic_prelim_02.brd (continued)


Board: 2 copper layers, 68.6 x 53.3 mm, 72 parts (1 on the bottom side), 67 nets.

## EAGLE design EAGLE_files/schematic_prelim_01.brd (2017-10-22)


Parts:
AD: PINHD-1X6; 1X06
C1, C2, C4, C5, C6, C7: 100n; C0603-ROUND
C3, C8: 1u; C0603-ROUND
C9, C10, C11, C12: 22p; C0603-ROUND
C13: 0.1µF; _0805
C14, C15: 10µF; _0805
D1: M7; SMB
F1: 500mA; L1812
GROUND: SJ
IC1: MC33269ST-5.0T3; SOT223
IC2: MC33269D-5.0; DPACK
ICSP, ICSP1: ICSP; 2X03
IOH: PINHD-1X8; 1X08
IOL: PINHD-1X8; 1X08
JP1: HEADER-1X770MIL; 1X07_ROUND_70
L: YELLOW; CHIP-LED0805
L1: BLM21; 0805
LED1: 45-21/LK2C-B38452C4CB2/2T; EVERLIGHT_45-21
ON: GREEN; CHIP-LED0805
PC1, PC2: 47u; PANASONIC_D
POWER: PINHD-1X6; 1X06
Q1, Q2: 16MHz; QS
Q3, Q4, Q5: BSS138; SOT23-WIDE
R1, R2: 1M; R0603-ROUND
R3: 27R; R0603-ROUND
R4, R5, R6, R7, R9: 10K; _0805
R8: TBD; _0805
RESET: TS42
RESET-EN: SJ
RN1: 10K; CAY16
RN2, RN4: 1K; CAY16
RN3: 22R; CAY16
RX: YELLOW; CHIP-LED0805
T1: FDN304V; SOT-23
TX: YELLOW; CHIP-LED0805
U1: LM358D; SO08
U2: LP2985-33DBVR; SOT23-DBV
U3: ATMEGA8U2-MU; QFN32
U4: TCS34725; TCS3472_FN6
U5: RT9193; SOT23-5
U$3, U$4, U$6: FIDUCIALMOUNT; FIDUCIA-MOUNT
UBOOT: SJ
X1: DC21MMX; DC-21MM
X2: PN61729
Y1, Y2: 16MHz; RESONATOR
Z1, Z2: PGB1010604; CT/CN0603
ZIC1: ATMEGA8; DIL28-3

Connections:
5-GND: RESET.5 (5-GND)
+3V3: C3.2, C13.1, C15.1, JP1.3, POWER.2, Q3.1 (G), Q4.1 (G), R4.2, R5.2, R8.1, R9.2, U1.2 (-IN), U2.5 (OUT), U4.P$1 (VDD), U5.5 (OUT)
+5V: C1.2, C2.2, C6.2, C7.1, IC1.2 (OUT), IC1.4 (OUT), IC2.2 (VO), ICSP.2, ICSP1.2, PC2.+, POWER.3, RN1.3 (1), RN1.5 (2), RN2.3 (1), RN2.4 (1), RN4.3 (1), RN4.4 (1), T1.2 (S), U1.8 (V+), U2.1 (IN), U2.3 (!EN), U3.4 (VCC), U3.32 (AVCC), ZIC1.7 (VCC), ZIC1.20 (AVCC)
AD0: AD.1, ZIC1.23 ((ADC0)PC0))
AD1: AD.2, ZIC1.24 ((ADC1)PC1)
AD2: AD.3, ZIC1.25 ((ADC2)PC2)
AD3: AD.4, ZIC1.26 ((ADC3)PC3)
AD4: AD.5, ZIC1.27 ((ADC4)PC4)
AD5: AD.6, ZIC1.28 ((ADC5)PC5)
AREF: C4.2, IOH.8, ZIC1.21 (AREF)
CMP: RN1.1, RN1.2 (1), U1.3 (+IN)
D+: RN3.5 (2), X2.3, Z1.1
D-: RN3.8 (2), X2.2, Z2.1
DTR: C5.1, U3.13 ((CTS/HWB/AIN6/TO/INT7)PD7), UBOOT.1
GATE_CMD: T1.3 (G), U1.1 (OUT)
GND: C1.1, C2.1, C3.1, C4.1, C6.1, C7.2, C9.2, C10.1, C11.2, C12.1, C13.2, C14.2, C15.2, GROUND.1, IC1.1 (GND/ADJ), IC2.1 (ADJ), ICSP.6, ICSP1.6, IOH.7, JP1.2, L.C, ON.C, PC1.-, PC2.-, POWER.4, POWER.5, Q5.2 (S), RESET.3, RESET.4, RN1.8 (2), U1.4 (V-), U1.5 (+IN), U1.6 (-IN), U2.2 (GND), U3.3 (GND), U3.EXP (PAD), U4.P$3 (GND), U5.2 (GND), UBOOT.2, X1.1, X1.3, Y1.2, Y2.2, ZIC1.8 (GND), ZIC1.22 (AGND)
INT: JP1.6, U4.P$5 (INT)
IO0: IOL.1, RN4.2 (1), ZIC1.2 ((RXD)PD0)
IO1: IOL.2, RN4.1, ZIC1.3 ((TXD)PD1)
IO2: IOL.3, ZIC1.4 ((INT0)PD2)
IO3: IOL.4, ZIC1.5 ((INT1)PD3)
IO4: IOL.5, ZIC1.6 ((T0)PD4)
IO5: IOL.6, ZIC1.11 ((T1)PD5)
IO6: IOL.7, ZIC1.12 ((AIN0)PD6)
IO7: IOL.8, ZIC1.13 ((AIN1)PD7)
IO8: IOH.1, ZIC1.14 ((ICP)PB0)
IO9: IOH.2, ZIC1.15 ((OC1)PB1)
LED_EN: JP1.7, Q5.1 (G), R9.1
M8RXD: RN4.7 (2), U3.9 ((TXD1/INT3)PD3)
M8TXD: RN4.8 (2), U3.8 ((RXD1/AIN1/INT2)PD2)
MISO: ICSP.1, IOH.5, ZIC1.18 ((MISO)PB4)
MISO2: ICSP1.1, U3.17 ((PD0/MISO/PCINT3)PB3)
MOSI: ICSP.4, IOH.4, ZIC1.17 ((MOSI)PB3)
MOSI2: ICSP1.4, U3.16 ((PDI/MOSI/PCINT2)PB2)
unnamed: LED1.K (C), Q5.3 (D)
unnamed: L.A, RN2.1, RN2.2 (1)
unnamed: ON.A, RN4.5 (2), RN4.6 (2)
unnamed: LED1.A, R8.2
unnamed: RN2.6 (2), RX.A
unnamed: RN2.5 (2), TX.A
PWRIN: D1.A, X1.2
RD+: RN3.4 (1), U3.29 (D+)
RD-: RN3.1, U3.30 (D-)
RESET: C5.2, ICSP.5, POWER.1, RESET.1, RESET.2, RESET-EN.1, RESET-EN.2, RN1.4 (1), ZIC1.1 (RESET)
RESET2: ICSP1.5, RN1.6 (2), U3.24 (RESET(PC1/DW))
RXLED: RX.C, U3.10 ((INT5/AIN3)PD4)
SCK: ICSP.3, IOH.6, RN2.7 (2), RN2.8 (2), ZIC1.19 ((SCK)PB5)
SCK2: ICSP1.3, U3.15 ((SCLK/PCINT1)PB1)
SCL_3V: Q4.2 (S), R4.1, U4.P$2 (SCL)
SCL_5V: JP1.4, Q4.3 (D), R7.1
SDA_3V: Q3.2 (S), R5.1, U4.P$6 (SDA)
SDA_5V: JP1.5, Q3.3 (D), R6.1
SS: IOH.3, ZIC1.16 ((SS)PB2)
TXLED: TX.C, U3.11 ((XCK/AIN4/PCINT12)PD5)
UGND: C8.2, GROUND.2, L1.1, U3.28 (UGND), X2.4
USBVCC: F1.1, T1.1 (D), U3.31 (UVCC)
USHIELD: L1.2, X2.P$1, X2.P$2, Z1.2, Z2.2
VIN: C14.1, D1.C, IC1.3 (IN), IC2.3 (VI), JP1.1, PC1.+, POWER.6, R6.2, R7.2, RN1.7 (2), U5.1 (IN), U5.3 (EN)
VUCAP: C8.1, U3.27 (UCAP)
XT1: C9.1, Q1.2, R1.1, R3.2, Y1.3
XT1R: R3.1, U3.1 (XTAL1)
XT2: C11.1, Q1.1, R1.2, U3.2 (XTAL2(PC0)), Y1.1
XTAL1: C10.2, Q2.2, R2.1, Y2.3, ZIC1.9 (XTAL1)
XTAL2: C12.2, Q2.1, R2.2, Y2.1, ZIC1.10 (XTAL2)
XUSB: F1.2, X2.1

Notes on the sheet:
Arduino UNO Reference Design
USB boot En
Reference Designs ARE PROVIDED "AS IS" AND "WITH ALL FAULTS". Arduino DISCLAIMS ALL OTHER WARRANTIES, EXPRESS OR IMPLIED,
Arduino may make changes to specifications and product descriptions at any time, without notice. The Customer must not
REGARDING PRODUCTS, INCLUDING BUT NOT LIMITED TO, ANY IMPLIED WARRANTIES OF MERCHANTABILITY OR FITNESS FOR A PARTICULAR PURPOSE
rely on the absence or characteristics of any features or instructions marked "reserved" or "undefined." Arduino reserves
these for future definition and shall have no responsibility whatsoever for conflicts or incompatibilities arising from future changes to them.
The product information on the Web Site or Materials is subject to change without notice. Do not finalize a design with this information.
Color Sensor TCS34725



Board: 2 copper layers, 68.6 x 53.3 mm, 72 parts (2 on the bottom side), 64 nets.

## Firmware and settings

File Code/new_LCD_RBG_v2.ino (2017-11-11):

/*
Uses the 326 LCD and the TCS34725 to display the color (on the LCD).
Version 2.0 - Updated the ambient 
*/

#include <SPI.h>
#include <Wire.h>
#include <Adafruit_GFX.h>
#include <Adafruit_SSD1306.h>
#include "Adafruit_TCS34725.h"

// set to false if using a common cathode LED
#define commonAnode true
// If using software SPI (the default case):
#define OLED_MOSI   9
#define OLED_CLK   10
#define OLED_DC    11
#define OLED_CS    12
#define OLED_RESET 13
/* Uncomment this block to use hardware SPI
#define OLED_DC     6
#define OLED_CS     7
#define OLED_RESET  8
Adafruit_SSD1306 display(OLED_DC, OLED_RESET, OLED_CS);
*/

#define NUMFLAKES 10
#define XPOS 0
#define YPOS 1
#define DELTAY 2

#define LOGO16_GLCD_HEIGHT 16 
#define LOGO16_GLCD_WIDTH  16 
static const unsigned char PROGMEM logo16_glcd_bmp[] =
{ B00000000, B11000000,
  B00000001, B11000000,
  B00000001, B11000000,
  B00000011, B11100000,
  B11110011, B11100000,
  B11111110, B11111000,
  B01111110, B11111111,
  B00110011, B10011111,
  B00011111, B11111100,
  B00001101, B01110000,
  B00011011, B10100000,
  B00111111, B11100000,
  B00111111, B11110000,
  B01111100, B11110000,
  B01110000, B01110000,
  B00000000, B00110000 };

#if (SSD1306_LCDHEIGHT != 32)
#error("Height incorrect, please fix Adafruit_SSD1306.h!");
#endif

Adafruit_SSD1306 display(OLED_MOSI, OLED_CLK, OLED_DC, OLED_RESET, OLED_CS);
Adafruit_TCS34725 tcs = Adafruit_TCS34725(TCS34725_INTEGRATIONTIME_50MS, TCS34725_GAIN_4X);

void setup() {
  
  Serial.begin(9600);
  //326 LCD init start
  // by default, we'll generate the high voltage from the 3.3v line internally! (neat!)
  display.begin(SSD1306_SWITCHCAPVCC);
  // init done

  //RGB sensor init start
  if (tcs.begin()) {
    Serial.println("Found sensor");
  } else {
    Serial.println("No TCS34725 found ... check your connections");
    while (1); // halt!
  //init done
  }
  //Clear what was last on the screen
  display.clearDisplay();
}

void loop() {
  uint16_t clear, red, green, blue;

  tcs.setInterrupt(false);      // turn on LED

  delay(60);  // takes 60ms to read 
  
  tcs.getRawData(&red, &green, &blue, &clear);

  tcs.setInterrupt(true);  // turn off LED
  
  Serial.print("C:\t"); Serial.print(clear);
  Serial.print("\tR:\t"); Serial.print(red);
  Serial.print("\tG:\t"); Serial.print(green);
  Serial.print("\tB:\t"); Serial.print(blue);

  //Figure out some basic hex code for visualization
  uint32_t sum = clear;
  float r, g, b;
  r = red; r /= sum;
  g = green; g /= sum;
  b = blue; b /= sum;
  r *= 256; g *= 256; b *= 256;
  Serial.print("\t");
  Serial.print((int)r, HEX); Serial.print((int)g, HEX); Serial.print((int)b, HEX);
  Serial.println();
  //Print a message to the LCD.
  if(clear < 1500)
    {
    // text display tests
    display.setTextSize(2);
    display.setTextColor(WHITE);
    display.setCursor(0,0);
    display.println("Ambient");
    display.display();
    }
  else if(r > b & g > b){ //yellow
    // text display tests
    display.setTextSize(2);
    display.setTextColor(WHITE);
    display.setCursor(0,0);
    display.println("Yellow");
    display.display();
  }
  else if(r > g & r > b){ //red
    // text display tests
    display.setTextSize(2);
    display.setTextColor(WHITE);
    display.setCursor(0,0);
    display.println("Red");
    display.display();
  }
  else if(g > r & g > b){ //green
    // text display tests
    display.setTextSize(2);
    display.setTextColor(WHITE);
    display.setCursor(0,0);
    display.println("Green");
    display.display();
  } 
  else if(b > r || b > g){ //blue
    // text display tests
    display.setTextSize(2);
    display.setTextColor(WHITE);
    display.setCursor(0,0);
    display.println("Blue");
    display.display();
    }
  else{ //error
    // text display tests
    display.setTextSize(2);
    display.setTextColor(WHITE);
    display.setCursor(0,0);
    display.println("Error");
    display.display();
  } 

  delay(2000); //Keep the last message to the screen for 2 sec
  display.clearDisplay();
}

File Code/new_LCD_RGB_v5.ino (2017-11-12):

/*
Group 14
ECE 411
11/11/2017


Short description: 
_____________________________________________________________________________________________________________________________
                  Uses the TCS34725 RGB sensor to detect a color and the 326 OLED actuator to display the color detected.
_____________________________________________________________________________________________________________________________


Long description: 
_____________________________________________________________________________________________________________________________
                  The TCS34725 RGB sensor allows for detection of clear, red, green, and blue light as distinct components
		  of incident light (to the sensor). Each sensor value (for clear, red, green, and blue) is a base-ten number, 
		  which can be used to distinguish different colors from each other. There are limitations to the capability 
		  of this device. For instance, detecting “light green” versus “dark green” could be difficult if not impossible 
		  because the RGB sensor readings are close to other colors. Also, unless the object is within 1 cm or less of 
		  the RGB sensor's photodiode array, the sensor's accuracy becomes worse. (Each photodiode in the array is 
		  responsible for one of the detected values of clear, red, green, and blue, which are controlled internally
		  by a Finite State Machine.) The OLED uses Serial Peripheral Interface (SPI) to communicate with the Arduino.
		  
		  Expected input range (RGB sensor values): [0, 20,0000+] (dimensionless positive integers)
		  Expected output (OLED actuator text): "Ambient", "Black", "Gray", "Blue", "Red", "Yellow", "Green", "Purple",
		  				"Pink", "Orange", "Brown", "Retry" (string of characters)
						
		  If the RGB's LED pin is grounded, then the program will display the last detected label. Once the LED pin 
		  is ungrounded, the OLED will start to detect new colors again. The program displays the color detected on 
		  the OLED, which can (among other things) display white font on a black background, or black font on a white 
		  background. 
		  
		  This program detects ambient, black, gray, blue, red, yellow, green, purple, brown, pink, and orange, 
		  using the RGB sensor. If the RGB sensor data does not map to one of these labels, then it displays "Retry"
		  until it detects a known label mapping. 
		  
		  The control logic for this program operates under the following assumption: a solid object is presented 
		  to the RGB sensor, within (or less than) 1 cm. The OLED's LED pin becomes ungrounded (after previously
		  being grounded), and gets the RGBC values of the object. Then, an if-else structure determines which color
		  was detected. Multiple solid objects of distinct colors were tested such that the unique colors tested
		  were mapped to the following ranges for R, G, and B:
		  
		  r_l < R < r_h ; 		g_l < G < g_h ; 		b_l < B < b_h;
		  
		  where the _l and _h subscripts indicate the lower and higher bounds of the detected value, respectively.
		  This means that after presenting a red object to the sensor, the values for R, G, and B can be approximated
		  using the Serial Monitor. Once approximated, the lower and higher bounds that red could assume were 
		  implemented in the control structure (shown in the .cpp file for the helper functions).
		  
		  Helper functions from the RGB_OLED_Helper_Functions.h file were created by our team to facilitate the 
		  heavy-lifting for the program. 
_____________________________________________________________________________________________________________________________


Version 5.0 
_____________________________________________________________________________________________________________________________
                 Detects white (ambient), black, red, orange, yellow, green, blue, brown, purple, and pink.
                 Stores the last detected color if the LED pin is grounded.
	         Uses functions to increase: abstraction, modularity, and maintainability.
_____________________________________________________________________________________________________________________________
*/

//Get libraries of code for functions needed in this program
#include <SPI.h>
#include <Wire.h>
#include <Adafruit_GFX.h>
#include <Adafruit_SSD1306.h>
#include "Adafruit_TCS34725.h"
#include "RGB_OLED_Helper_Functions.h"

//Objects for the OLED
Adafruit_SSD1306 display(OLED_MOSI, OLED_CLK, OLED_DC, OLED_RESET, OLED_CS);
Adafruit_TCS34725 tcs = Adafruit_TCS34725(TCS34725_INTEGRATIONTIME_50MS, TCS34725_GAIN_4X);

//Global variables for storing the RGB sensor data
uint16_t clear, red, green, blue;

//Execute void setup() function only once
void setup() {
  if(init_RGB_OLED())
	      Serial.println("Initialization successful\n");
  else
	      Serial.println("Initialization failed\n");  
}

//Execute void loop() function forever, as long as the circuit has power
void loop() {
  //Check RGB sensor and get the data, then print it to the Serial Monitor
  get_and_print_RGB();
  //Get the color label (clabel) and print it to the OLED
  get_and_print_clabel();
  //Clear the last color detected
  display.clearDisplay(); 
}

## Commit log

2017-10-12 Create modified_scrolling
    First attempt modifying the auto-scroll program from the Arduino RedBoard library.
    Scrolls the text, from the bottom right to the left of the LCD: "ECE Team 14 Rulezz"
2017-10-26 prelim board 2
    [schematic_prelim_02.brd, schematic_prelim_02.sch]
2017-10-28 Create audio_test.ino
    This code works on the Redboard.
    We are still figuring out the correct parameters to make the audio file(s) play perfectly.
    Currently, we get a quick squirrel voice or a long, static voice.
    [audio_test.ino]
2017-10-30 Create Enclosure Design (3D Print)
2017-11-03 Create algorithm_color_LCD.txt
    Algorithm for the integrated color sensor and LCD actuator.
2017-11-11 Create new_LCD_RGB.ino
    First draft of the 326 LCD with the RGB sensor.
    LCD works, but the circuit for the RGB sensor doesn't seem to be operating correctly.
    [new_LCD_RGB.ino]
2017-11-12 Bill of Materials v1 from EAGLE schematic
    [BOM_v1.csv]
2017-11-12 Create RGB_OLED.txt
    Algorithm for the RGB sensor and OLED actuator
    Describes the high-level view of the program.
    The program uses an RGB sensor and an LCD actuator.
2017-11-13 Board semi-final version before talking to teacher
    [Team_14_03a.brd]
2017-11-13 Updated schematic
2017-11-13 deleted incorrect file
    [Team_14_03a.brd]
2017-11-13 updated file name
    [Team_14_DRAFT_02.brd]
2017-11-14 updated files
    update files
    [Adafruit 128x64 Mono OLED PCB v2.sch, Adafruit_128x64_Mono_OLED_PCB_v2.brd, Adafruit_128x64_Mono_OLED_PCB_v2.sch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]
2017-11-14 tweaked board files
    Tweaked lables on board files
    [Team_14_PCB_Ver4.5.brd, Team_14_PCB_Ver4.5.sch]
2017-11-14 fixed version number
    Fixed version number
    [Team_14_PCB_Ver4.5.brd]
2017-11-16 Pre-print update
    Updated board with final fixes before printing
    [Team_14_PCB_Ver4.5.brd, Team_14_PCB_Ver4.5.sch]
2017-11-22 new images
    added updated board and schematic images
2017-11-22 Fixed label of SCL_5V line
    Fixed label of SCL_5V line - was accidentally re-named SDA_5V1
    [Team_14_PCB_Ver4.5.1.brd, Team_14_PCB_Ver4.5.1.sch]
2017-11-28 Create Enclosure

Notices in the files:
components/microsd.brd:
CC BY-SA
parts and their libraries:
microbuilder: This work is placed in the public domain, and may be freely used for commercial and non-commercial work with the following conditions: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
